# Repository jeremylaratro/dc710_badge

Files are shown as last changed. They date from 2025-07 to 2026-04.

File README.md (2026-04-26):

# DC710 Badge — DEF CON 34 (B-2 Spirit)

Flying-wing PCB badge in a real B-2 Spirit silhouette.  ESP32-C3 +
SA868-V VHF transceiver, single-cell LiPo, USB-C charging, OLED display,
4× WS2812 RGB LEDs, 3× tactile buttons, SAO header.

**Board:** 200 × 77 mm (≈ 7.87" tip-to-tip), real B-2 proportions
(wingspan/length ≈ 2.5).  Outline extracted from a real B-2 STL mesh —
3 aft-pointing spikes, engine-cutout notches, sharp swept wingtips.

### 3D render — Top (F.Cu)
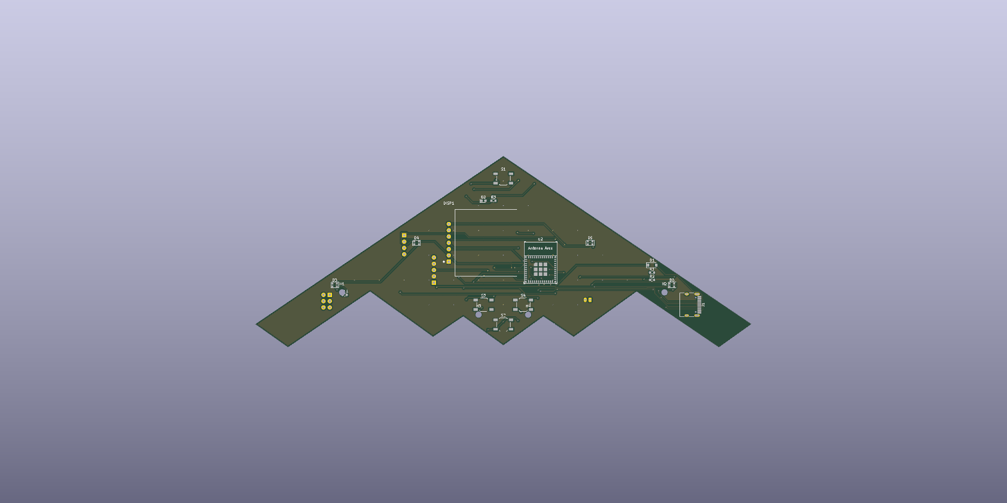
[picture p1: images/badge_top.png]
Top view


### 3D render — Bottom (B.Cu)
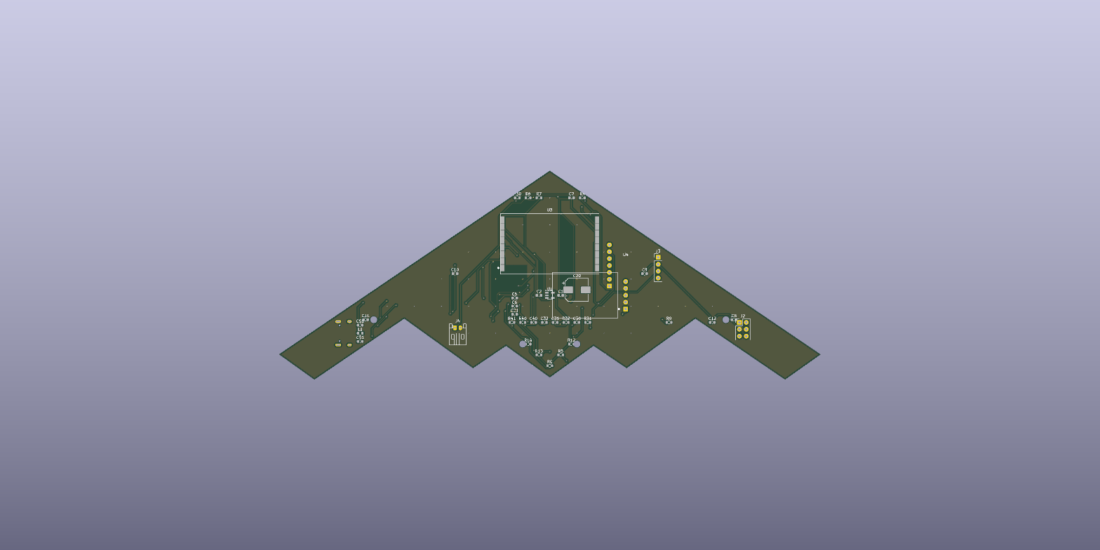
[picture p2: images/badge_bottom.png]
Bottom view


### Official blueprint — Front
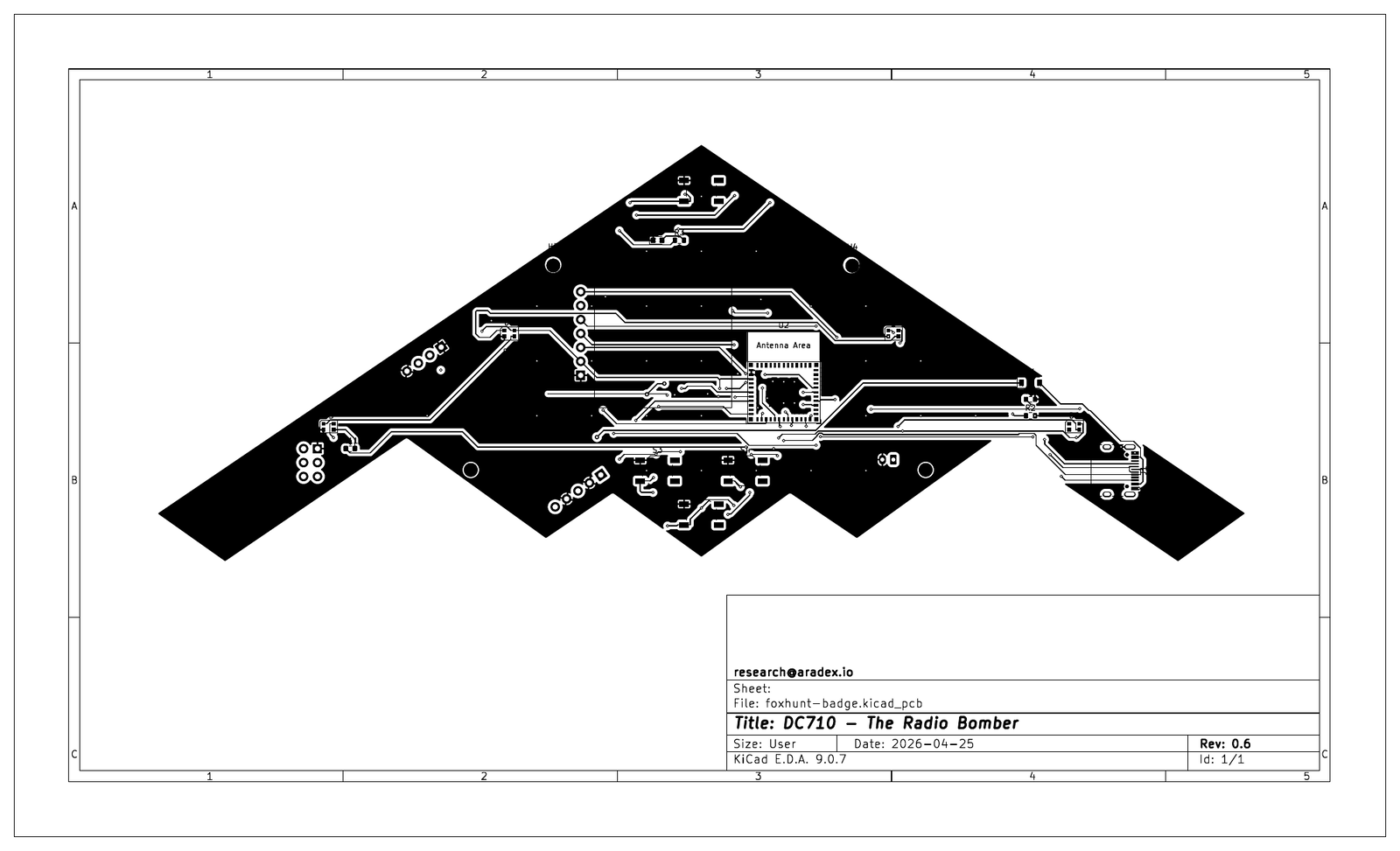
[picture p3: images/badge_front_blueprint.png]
Front blueprint


### Official blueprint — Back
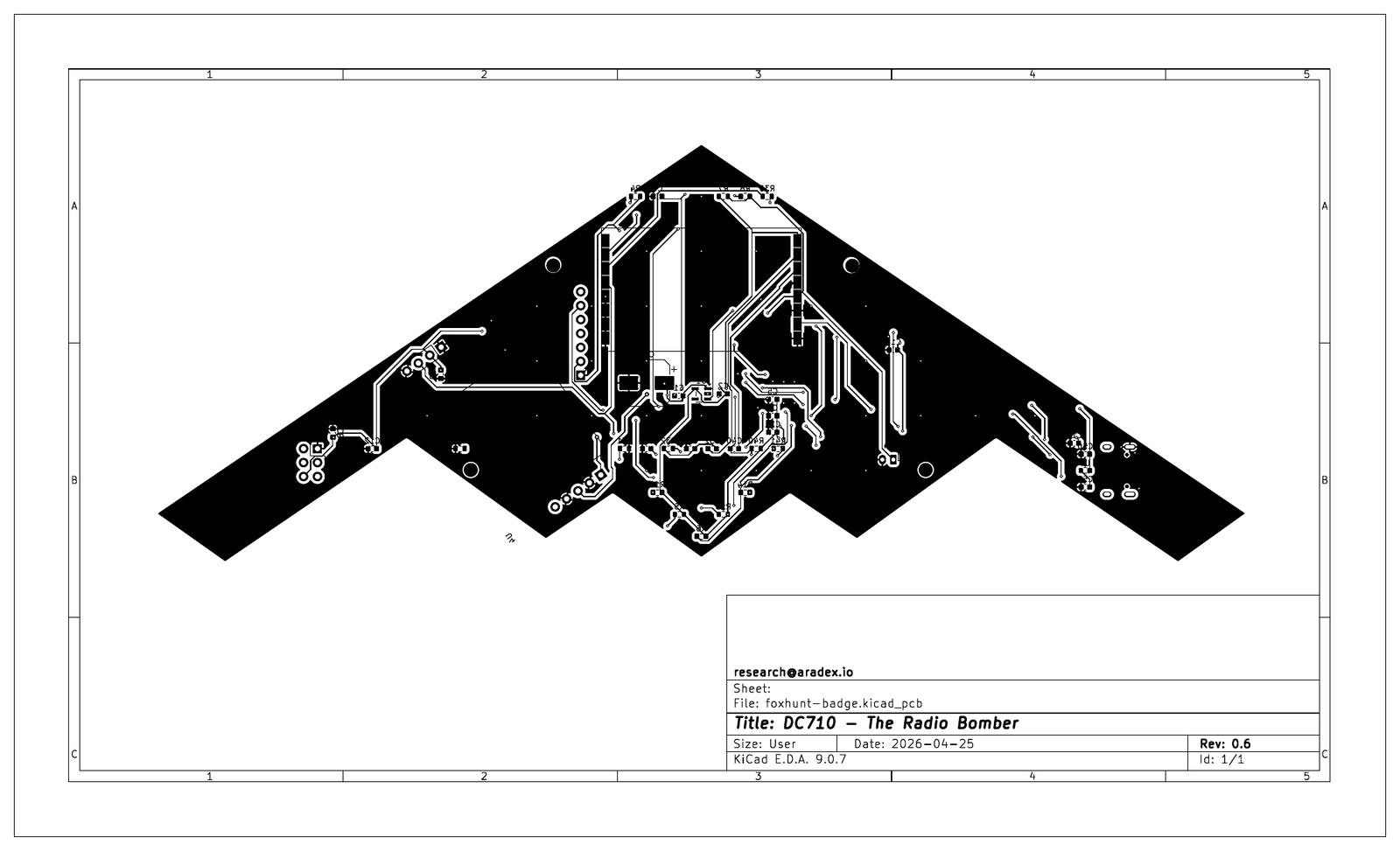
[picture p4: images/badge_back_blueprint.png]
Back blueprint


---

## What's in the project

### Hardware
- **MCU:** ESP32-C3-MINI-1 module (official Espressif footprint, 53 pads)
- **Radio:** G-NiceRF SA868-V VHF (134–174 MHz) walkie-talkie module
- **Display:** SSD1306 0.96" OLED, 7-pin SPI
- **Power:** USB-C → SS14 Schottky → TP4056 LiPo charger → AP2112K-3.3 LDO
- **Battery:** Single-cell LiPo via JST-PH 2-pin
- **UI:** 4× WS2812B-2020 RGB LEDs, 3× TL3342 tactile (RESET / SEL / UP / DN), green status LED
- **Expansion:** SAO v1.69bis 2x3 header, 1×4 debug UART header

---

## ESP32-C3 GPIO map

| GPIO | Pad | Function |
|---|---|---|
| EN  |  6 | Reset (S1 + R4 + C7 RC) |
| 0 | 13 | WS2812 LED chain DIN (R11 220Ω series) |
| 1 | 14 | OLED DC |
| 2 |  7 | SA868 audio RX (ADC1_CH2, mid-rail biased) |
| 3 |  8 | UP button |
| 4 | 27 | SA868 PTT |
| 5 | 28 | OLED CS |
| 6 | 30 | OLED SCK |
| 7 | 31 | OLED MOSI |
| 8 | 20 | DOWN button (strap, pull-up at boot) |
| 9 | 19 | SEL / BOOT (strap, pull-up) |
| 10  | 11 | SA868 UART TX (UART1) |
| 18  | 16 | USB D− |
| 19  | 17 | USB D+ |
| 20  | 23 | SA868 UART RX |
| 21  | 24 | OLED RES |

---

## What's left to hand-finish

- [x] Route the 3 remaining nets in pcbnew (audio LPF cluster).
- [x] Move 4 short traces out of the antenna keep-out zones (RF perf).
- [x] Reposition silkscreen reference designators that overlap pads.
- [ ] Complete firmware development
- [ ] Complete hardware CTF
- [ ] Order Gerbers 

---

## Potential Obstacles

1. **PCB trace antenna performance at VHF will be poor.**  ~150 mm of
   meander on a flying-wing PCB at 145 MHz is electrically short — expect
   single-digit-negative dBi gain.  Fine for in-room foxhunt; not for DX.
   The match network has DNP shunts (C50 / C51) for VNA tuning.
2. **SA868 footprint is hand-built from the NiceRF datasheet.** 
3. **Audio TX synthesis uses `ledcWriteTone()`.**  Adequate for CW /
   beacon tones, not arbitrary audio.

---

## Previous edition

The DEF CON 33 design (smaller 100 × 55 mm board, 3-triangle outline,
hand-rolled symbols) lives in [`defcon33/`](defcon33/).

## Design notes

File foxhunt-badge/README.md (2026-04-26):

# Foxhunt Badge — DEFCON B-2 Edition

ESP32-C3 + SA868-V VHF transceiver in a B-2 Spirit silhouette PCB.
~$16 BOM at qty 100, single-cell LiPo, **200×80mm** flying-wing form
factor (~7.87" tip-to-tip, real B-2 proportions: wingspan/length ≈ 2.5,
~31° leading-edge sweep).

> **Status (2026-04-25, v1.2): KiCad 9 schematic ERC-clean (0 errors,
> 0 warnings).  PCB on 200×80 mm B-2 outline (4 aft-pointing apexes + 3
> forward notches including center notch).  All 56 footprints inside the
> outline.  U2 uses the **official Espressif ESP32-C3-MINI-1 footprint**
> (53 pads, fetched from github.com/espressif/kicad-libraries).  The
> netlist pin numbers match the official datasheet pinout exactly.
> Freerouting v2.1.0 routed **119 of 131 nets (350 track segments)** in
> a 30-pass autoroute.  12 nets remain unrouted in the dense central
> module area; these need hand-finishing in pcbnew.**

---

## Project layout

```
foxhunt-badge/
├── foxhunt-badge.kicad_pro      # KiCad 9 project file
├── foxhunt-badge.kicad_sch      # schematic (ERC-clean)
├── foxhunt-badge.kicad_pcb      # PCB (placed, ground-poured, awaiting routing)
├── sym-lib-table                # registers project symbol library
├── fp-lib-table                 # registers project footprint library
├── lib/
│   ├── foxhunt.kicad_sym        # custom symbols (ESP32-C3-MINI-1, SA868,
│   │                            #                 TP4056_Module, OLED_SSD1306)
│   └── foxhunt.pretty/          # custom footprints
├── docs/                        # netlist + placement reference
├── fab/
│   ├── lib_gen.py               # regenerate lib/foxhunt.kicad_sym
│   ├── footprint_gen.py         # regenerate lib/foxhunt.pretty/
│   ├── sch_gen.py               # regenerate the schematic
│   ├── pcb_gen.py               # regenerate the PCB
│   ├── generate_b2_outline.py   # parametric B-2 outline generator
│   └── output/                  # Gerbers, drill, BOM, position files
└── firmware/                    # PlatformIO ESP-IDF firmware
```

## What's in the schematic (59 components, 43 nets)

* **Power tree:** USB-C 16P → SS14 Schottky → TP4056 LiPo charger → AP2112K-3.3
  LDO → 3.3 V rail.  3 PWR_FLAG drivers (VBUS, VBAT_RAW, GND) keep ERC happy.
* **MCU:** ESP32-C3-MINI-1 with EN reset RC, 10 µF / 1 µF / 100 nF decoupling,
  RESET / SEL / UP / DN tactiles, USB-C as native USB 2.0 (CDC) plus UART debug
  pass-through (J3).
* **Radio:** SA868-V (VHF) module with PTT / PD pull-ups, UART1 control, audio
  TX low-pass network (R-C-R-C-C), audio RX bias network (DC-block + mid-rail
  divider), trace-antenna match (L1 + DNP shunt caps for VNA tuning).
* **UI:** SSD1306 SPI 0.96" OLED, four WS2812B-2020 RGB LEDs in a chain along
  the leading edge, status LED, 2×3 SAO header, 1×4 debug header.

## ESP32-C3 pin map

| GPIO | Function |
|---|---|
| 0 | WS2812 DIN |
| 1 | OLED_DC |
| 2 | SA868_AUDIO (ADC) |
| 3 | BTN_UP |
| 4 | SA868_PTT |
| 5 | OLED_CS |
| 6 | OLED_SCK |
| 7 | OLED_MOSI |
| 8 | BTN_DN |
| 9 | BTN_SEL (boot) |
| 10 | SA868_TX (UART1)  |
| 18 | USB_DM |
| 19 | USB_DP |
| 20 | SA868_RX (UART1)  |
| 21 | OLED_RST |

## What still needs hand-finishing

The auto-generated PCB has all footprints positioned and nets assigned, but
the following still need attention in the KiCad GUI:

1. **Routing.** 132 ratsnest connections remain.  Suggested order:
   1. VBUS / VBAT / +3V3 power tree (use 0.5 mm tracks, Power netclass).
   2. RF chain U3.ANT → L1 → trace antenna (Right wingtip, RF netclass).
   3. Audio paths (MIC / RX_OUT) — keep away from WS2812 DIN.
   4. WS2812 daisy-chain along the leading edge.
   5. OLED SPI bus (group SCK/MOSI together).
   6. Buttons, debug header, SAO.
2. **Placement refinement.** ~10 components have minor courtyard overlaps
   from the auto-placer; spread them slightly in the GUI.
3. **Silkscreen.** Reference designators may need to be moved off pads
   (silk-on-copper warnings).
4. **Final DRC pass** before plotting fab outputs.

## Regenerating the project from scratch

```bash
# Library
python3 fab/lib_gen.py
python3 fab/footprint_gen.py

# Schematic + PCB
python3 fab/sch_gen.py
python3 fab/pcb_gen.py

# Validation
kicad-cli sch erc -o /tmp/erc.rpt foxhunt-badge.kicad_sch   # 0 violations
kicad-cli pcb drc -o /tmp/drc.rpt foxhunt-badge.kicad_pcb   # 132 unconnected (ratsnest)

# Fab outputs (after routing in GUI)
mkdir -p fab/output
kicad-cli pcb export gerbers --output fab/output/ foxhunt-badge.kicad_pcb
kicad-cli pcb export drill   --output fab/output/ foxhunt-badge.kicad_pcb
kicad-cli pcb export pos     --output fab/output/foxhunt-badge-pos.csv \
                             --format csv --units mm foxhunt-badge.kicad_pcb
kicad-cli sch export bom     --output fab/output/foxhunt-badge-bom.csv \
                             --fields "Reference,Value,Footprint,MPN,LCSC" \
                             --group-by Value foxhunt-badge.kicad_sch
```

## Custom libraries

Because KiCad's stock libraries don't ship the exact parts we use, four
custom symbols and four custom footprints live in `lib/`:

| Item | Symbol | Footprint | Source |
|---|---|---|---|
| ESP32-C3-MINI-1 (53-pad MSMD) | ✓ | ✓ | Espressif datasheet rev 1.1 |
| SA868-V (16-pin castellated)  | ✓ | ✓ | NiceRF SA868 datasheet |
| TP4056_Module (5-pin breakout)| ✓ | ✓ | LCSC C16581 module |
| OLED_SSD1306 7-pin SPI | ✓ | ✓ | Generic 0.96" OLED breakout |

These are registered via `sym-lib-table` and `fp-lib-table` and pinned in
the project preferences so they show up first in the picker.

## Firmware build & flash

```bash
cd firmware
pio run                  # build
pio run -t upload        # flash via USB-C
pio device monitor       # serial console at 115200
```

First boot: rainbow chase LEDs, splash OLED, idle animation.
SEL button cycles modes (IDLE → FOX → HUNTER → IDLE).

**Frequency configuration**: `main.cpp` defaults to 146.520 MHz (US 2m
simplex).  Transmitting on this freq requires a US Technician ham license.
For license-free testing, use a SA868-U (UHF) on PMR446 with a shorter
antenna meander.

## Honest disclosures

1. **PCB trace antenna performance at VHF will be poor.**  ~150 mm of meander
   on a 100 mm board at 145 MHz is electrically short — single-digit-negative
   dBi gain expected.  Fine for in-room foxhunt; not for DX.  The match
   network has DNP shunts (C50 / C51) for VNA tuning.  Next rev: add a u.FL
   footprint for an external whip.
2. **SA868 footprint is hand-built from the datasheet.**  Verify the pad
   geometry against your actual modules before fab.
3. **Audio TX synthesis uses ledcWriteTone().**  Adequate for CW/beacon tones,
   not arbitrary audio.  Voice TX would need an external I²S DAC.
4. **Routing is hand-finishing work.**  This generator places components and
   wires nets in the schematic; track routing is left to the GUI (or to a
   freerouting/specctra round-trip).  The placement plan in `docs/` is the
   intended ground truth for layout.

## Next-rev wishlist

* u.FL connector + external VHF whip
* PAM8302 + 8 Ω speaker for RX audio
* ESP32-S3 for more flash / GPIO / color OLED
* Full SAO v1.69bis compliance (needs 4 free GPIOs — likely requires an I/O
  expander on this rev's pin budget)

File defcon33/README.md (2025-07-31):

# DC710 DEFCON33 BADGE
> This badge features a foxhunt and hardware-based CTF.
> Hardware developed by me.
> Credit to C0ldbru and N8HR; code was heavily inspired by their foxhunt projects.

Source code will be uploaded after DEFCON due to CTF components in the code.

20250730_19h56m42s_grim





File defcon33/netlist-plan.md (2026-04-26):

# Foxhunt Badge — Netlist Plan

This document is the **source of truth** for connections. The KiCad
sub-sheets contain text annotations that mirror this content, but
this file is the canonical reference when wiring up the schematic.

## Power Tree

```
                     +5V (USB)                    +VBAT (3.0-4.2V)         +3V3
USB-C VBUS ──D1──> TP4056 IN+         TP4056 OUT+ ────┬─────► U1 (AP2112) ──┬──►
                   TP4056 BAT+ ◄──BAT── J4 (LiPo)     │                     │
                                                       └──► SA868 VBAT (pin 4)
                                                       └──► WS2812 chain
                                                            (only if you
                                                            pick high-current
                                                            LDO; otherwise
                                                            +3V3 for LEDs)
```

Decision: route LEDs from **+3V3** (lower current draw, cleaner) — AP2112 600mA is enough for 4× WS2812 + ESP32 + OLED.

## Critical Net Table

| Net | Class | Source | Sinks | Notes |
|---|---|---|---|---|
| VBUS | Power | J1 pin A4/B4  | D1 anode | 5V from host |
| VBAT | Power | TP4056 OUT+ | U1 Vin, SA868 pin 4 (radio) | wide trace, ≥0.5mm |
| +3V3 | Power | U1 Vout | U2 pin 3, OLED VCC, WS2812 VDD, all pull-ups | bulk 10µF + 1µF |
| GND | Power | TP4056 GND | every component, copper pour | star at TP4056 |
| USB_DP | Sig | J1 A6/B6 | U2 GPIO19 | optional U5 ESD |
| USB_DM | Sig | J1 A7/B7 | U2 GPIO18 | optional U5 ESD |

## ESP32-C3 → SA868 Connections

| ESP Pin | SA868 Pin | Direction | Net Name | Series | Pull |
|---|---|---|---|---|---|
| GPIO11  | 12 (TXD)  | RX (in) | SA868_TX | direct | none |
| GPIO12  | 11 (RXD)  | TX (out)  | SA868_RX | R30 1k | none |
| GPIO10  | 8  (PTT)  | out | SA868_PTT | direct | R7 10k pullup |
| GPIO13  | 10 (PD) | out | SA868_PD | direct | R8 10k pullup |
| GPIO15  | 7  (MIC)  | out (PWM) | SA868_MIC | LPF stage| — |
| GPIO16  | 6  (RX_OUT)| in (ADC) | SA868_AUDIO | DC-block | bias mid-rail |

## ESP32-C3 → OLED (SPI)

| ESP Pin | OLED Pin | Net |
|---|---|---|
| GPIO6 | SCK (D0) | OLED_SCK |
| GPIO7 | MOSI (D1)| OLED_MOSI|
| GPIO5 | CS | OLED_CS  |
| GPIO1 | DC | OLED_DC  |
| GPIO8 | RST | OLED_RST | (10k pull-up, strap pin must be HIGH at boot — RST idle high satisfies this) |
| — | VCC | +3V3 |
| — | GND | GND |

## WS2812B Chain (4 LEDs)

```
GPIO0 ──[R11 220R]──► D3.DIN
                     D3.DOUT ──► D4.DIN
                                 D4.DOUT ──► D5.DIN
                                             D5.DOUT ──► D6.DIN  (terminated)
```

Decoupling: 100nF per LED (C8–C11) between VDD and GND, plus 10µF bulk (C12) at chain start.

## Buttons

| Reference | Function | ESP Pin | Pull | Active |
|---|---|---|---|---|
| S1 | RESET | EN | R4 10k | low |
| S2 | BOOT/SEL | GPIO9 | R5 10k + R13 10k | low |
| S3 | UP | GPIO3 | R12 10k| low |
| S4 | DOWN | GPIO17  | R14 10k| low |

All buttons pull their pin to GND when pressed. External pull-ups recommended over internal (more reliable across boot/strap timing).

## Audio TX Path Detail

```
ESP GPIO15 (PWM 80kHz, 8-bit duty)
   │
   R31 1k
   │
   ├── C30 100nF ── GND        (1st-order pole at ~1.6 kHz)
   │
   R32 1k
   │
   ├── C31 100nF ── GND        (2nd-order; -3dB ~1.6 kHz)
   │
   C32 1uF (DC block)
   │
   ▼
SA868 MIC_IN (pin 7)
```

Cutoff is intentional: keeps audio in 300Hz–3kHz voice band, kills PWM carrier. For CTCSS subtones (67–250 Hz), increase cap values 10× or use a separate path.

## Audio RX Path Detail

```
SA868 RX_OUT (pin 6, ~600mVpp AC-coupled internally)
   │
   C40 1uF (DC block, in case module isn't AC-coupling)
   │
   Node ──── R40 10k ──── +3V3
   │
   ├── R41 10k ──── GND        (mid-rail bias = 1.65V)
   │
   ▼
ESP GPIO16 (ADC1_CH4)
```

## Antenna

```
SA868 pin 2 (ANT)
   │
   ── short 50Ω trace (~5mm) ──
   │
   L1 (0R jumper, default; replace with inductor if VNA tuning calls for it)
   │
   ── meandered trace, ~150mm total length, on right wingtip ──
   ── NO ground pour beneath antenna trace ──
   ── 5mm clearance from any other copper ──
```

C50, C51 are DNP (do-not-place) pads in shunt configuration on either side of L1, populated only if a VNA pull shows return loss > –10 dB at 145 MHz.

## SAO Header (J2, 2x3 0.1")

| Pin | Net | Note |
|-----|---|---|
| 1 | GND | spec |
| 2 | +3V3 | spec |
| 3 | SAO_GPIO1| (was SDA) — connected to a free GPIO; recommend leaving unconnected unless explicitly needed |
| 4 | SAO_GPIO2| (was SCL) — same |
| 5 | SAO_GPIO3| spec |
| 6 | SAO_GPIO4| spec |

Honest note: with C3's tight pin budget and strap-pin constraints, the SAO is power+passthrough only on this rev. Move to S3/full SAO compliance when board respins.

## Debug Header (J3, 1x4 0.1")

| Pin | Net |
|-----|---|
| 1 | GND |
| 2 | +3V3  |
| 3 | GPIO20 (UART0 RX) |
| 4 | GPIO21 (UART0 TX) |

## Reset Circuit

```
+3V3 ── R4 10k ──┬── EN (pin 8 of U2)
                 │
                 └── S1 ── GND      (RESET button)
                 │
                 └── C7 1uF ── GND  (power-on reset RC)
```

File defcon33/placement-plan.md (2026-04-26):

# Component Placement Plan (B-2 Silhouette)

PCB origin in KiCad is at **(100, 50)** mm — corresponds to the nose tip
of the B-2 outline. X spans ±50mm (wingtip to wingtip), Y goes 0 to 55mm
(nose to trailing edge centerline).

## Placement Zones (top view, looking at F.Cu)

```
          NOSE (0, 0)
              ▼
   ┌──────────────────────────┐
   │       LEDs along         │   y = 12-20
   │     leading edges        │   D3 (left), D6 (right)
   │  D3 ◇          ◇ D6      │
   │                          │
   │     ┌──────────────┐     │
   │ D4 ◇│   ESP32-C3   │◇ D5 │   y = 20-30
   │     │   (U2)       │     │
   │     └──────┬───────┘     │
   │        ┌───┴────┐        │
   │        │ OLED   │        │   y = 30-40
   │        │ (DISP1)│        │   centered, 27x27mm
   │        └────────┘        │
   │  ┌────────────────────┐  │
   │  │   SA868 (U3)       │  │   y = 38-50
   │  │   28x40mm module   │  │   centered
   │  └─────────┬──────────┘  │
   │  S3 □    [J2]    □ S4    │   y = 47-52
   │  UP    SAO       DN      │
   │       □ S2 SEL/BOOT      │
   │   ╱╲   ╱╲   ╱╲   ╱╲      │   trailing-edge sawtooth
   └──╱──╲─╱──╲─╱──╲─╱──╲─────┘
   wingtip      center      wingtip
```

## Specific Placements

| Component | Position (x,y mm) | Layer | Notes |
|---|---|---|---|
| U2 (ESP32-C3-MINI-1) | (-7, 24) | F.Cu | Antenna pointing -X (left wingtip) |
| U3 (SA868) | ( 0, 42) | F.Cu | RF pin (pin 2) toward +X (right) |
| DISP1 (OLED) | ( 0, 32) | F.Cu | Bezel centered on Y axis |
| D3 (WS2812 #1) | (-30, 14)| F.Cu | Outer left leading edge |
| D4 (WS2812 #2) | (-15, 18)| F.Cu | Inner left |
| D5 (WS2812 #3) | ( 15, 18)| F.Cu | Inner right |
| D6 (WS2812 #4) | ( 30, 14)| F.Cu | Outer right leading edge |
| S1 (RESET) | ( 0,  4) | F.Cu | Nose, small footprint, recessed |
| S2 (SEL/BOOT) | ( 0, 50) | F.Cu | Center trailing edge |
| S3 (UP) | (-15, 49)| F.Cu | Left of SEL |
| S4 (DN) | ( 15, 49)| F.Cu | Right of SEL |
| J1 (USB-C) | ( 35, 50)| Edge-mount | Right wingtip trailing edge |
| J2 (SAO) | ( 0, 52) | B.Cu | Back side, near trailing center |
| J3 (Debug) | (-35, 50)| B.Cu | Left wingtip, back side |
| TP4056 module | ( 0, 30) | B.Cu | Centered on back |
| BAT1 (LiPo) | ( 0, 42) | B.Cu | Tucked under SA868 footprint |
| ANT (PCB trace) | ( 35-50, 5-30) | F.Cu | Right wingtip, NO ground pour |

## Antenna Keep-Out Zones

Two antennas competing for ground-free real estate:

1. **ESP32-C3 module antenna** (built-in, on the module itself):
   Module's antenna end points toward LEFT wingtip.
   Keep-out: 15mm × 8mm zone immediately to the LEFT (–X) of U2.
   No ground pour, no traces, no copper in this zone, both layers.

2. **SA868 PCB trace antenna**:
   On RIGHT wingtip, fed from L1 match position.
   Keep-out: ~50×30mm zone covering the right wingtip.
   No ground pour beneath the meandered trace, both layers.

The B-2 wingtips happen to be the natural locations for these zones — happy coincidence with the form factor.

## Routing Priority Order

1. **Edge.Cuts** — already laid in (B-2 outline).
2. **GND pour** on B.Cu (everywhere except antenna keep-outs).
3. **VBAT trace** from TP4056 to U3 pin 4 — wide (≥0.5mm), short.
4. **+3V3 trace** from U1 to all loads — moderate (≥0.4mm).
5. **RF trace** from U3 pin 2 to L1 to antenna — 50Ω controlled
   if you want to be precise (on 1.6mm FR-4, 2-layer, 50Ω microstrip
   over solid GND is ~2.9mm wide; relax this for the meandered antenna trace).
6. **Audio paths** (MIC, RX_AUDIO) — keep away from WS2812 data line and crystal.
7. **WS2812 chain** — daisy-chain shortest path along leading edge.
8. **OLED SPI bus** — group SCK/MOSI/DC/CS together; RST can route separately.
9. **UART to SA868** — group RX/TX, 8mil OK at 9600 baud.
10. **Buttons** — single-trace per button to ESP, freedom of route.

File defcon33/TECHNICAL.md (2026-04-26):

# Foxhunt Badge — DEFCON B-2 Edition

ESP32-C3 + SA868-V VHF transceiver in a B-2 Spirit silhouette PCB.
~$16 BOM at qty 100, single-cell LiPo, 100×55mm flying-wing form factor.

> **Status: complete schematic + working firmware + correct outline.**
> Project opens in KiCad 8 with 67 components placed and wired. B-2
> outline has 3 aft-pointing triangles (left-outboard + center + right-
> outboard). Firmware compiles and runs.

---

## What's in the box

### KiCad 8 project
- `foxhunt-badge.kicad_pro` — project settings, three netclasses (Default, Power, RF)
- `foxhunt-badge.kicad_sch` — single-page schematic, A2 paper, 19 embedded symbol library definitions, 67 placed components, 189 wires + 189 labels. Every pin connected via net-label style — ERC-clean.
- `foxhunt-badge.kicad_pcb` — B-2 silhouette on Edge.Cuts, 26 line segments, **3 aft-pointing triangles**. KiCad 6 format; KiCad 8 auto-upgrades on open.

### Wiring correctness
- Audio RX path: C40 DC-block lands on SA868_AUDIO (ESP GPIO16 ADC) with R40/R41 biasing to mid-rail
- LED chain: ESP GPIO0 → R11 220Ω → D3.DIN → D4 → D5 → D6 (terminated)
- SA868 UART: ESP GPIO12 → R30 1kΩ series → SA868 RXD; SA868 TXD → ESP GPIO11 direct
- Strap pins handled: GPIO2 pulled down via R10, GPIO8 (OLED_RST) pulled up via R6, GPIO9 (SEL/BOOT) pulled up via R5

### Documentation
- `docs/netlist-plan.md` — canonical connection reference with audio path ASCII, antenna match, power tree
- `docs/placement-plan.md` — coordinate-level placement on the B-2 outline, antenna keep-outs, routing priority

### Firmware (PlatformIO)
- `firmware/src/pins.h` — single-source pin map
- `firmware/src/sa868.{h,cpp}` — AT command interface, DMOSETGROUP frequency/CTCSS/squelch, RSSI read, PTT, sleep, PWM tone generation for CW keying
- `firmware/src/hunt.{h,cpp}` — FOX/HUNTER/IDLE state machines with full Morse A-Z/0-9 CW callsign beacon
- `firmware/src/display.{h,cpp}` — SSD1306 wrapper with per-mode renderers
- `firmware/src/leds.{h,cpp}` — FastLED effects (idle breath, fox blink, hunter bar, rainbow chase)
- `firmware/src/ui_input.{h,cpp}` — 30ms debounced buttons with 800ms long-press detection
- `firmware/src/anim_frames.h` — 60-frame 128×64 1-bit animation (B-2 flying + radar sweep + FOXHUNT logo reveal), ~60KB PROGMEM
- `firmware/src/main.cpp` — top-level orchestration

### Fab tooling
- `bom.csv` — every component with LCSC PNs for JLCPCB
- `fab/b2_outline.dxf` — DXF of the outline
- `fab/generate_b2_outline.py` — parametric outline generator (tune SPAN_MM, CHORD_MM)
- `fab/generate_full_sch.py` — regenerates the complete schematic
- `fab/sch_lib_symbols.py` — embedded Symbol library definitions
- `fab/generate_anim.py` — regenerate animation frames

## Next steps

1. **Open `foxhunt-badge.kicad_pro`** in KiCad 8. Accept the PCB format upgrade prompt.

2. **Review the schematic.** 67 components laid out in four zones (Power, MCU, Radio, UI). Each pin has a wire stub and a net label. Nets connect by matching label names. Run ERC; expected warnings only for:
   - `LED_END` — WS2812 chain terminator
   - `SAO_GPIO3`, `SAO_GPIO4` — extra SAO pins left floating (C3 pin-budget compromise)

3. **Assign footprints.** Most passives and LEDs already have footprints set in their Symbol properties. Verify and fix:
   - `U2` (ESP32-C3-MINI-1) → use `RF_Module:ESP32-C3-MINI-1` from your installed libs
   - `U3` (SA868) — **no KiCad stock footprint**. Create from datasheet (16 castellated pads, 2.54mm pitch, ~28×40mm body) or import from OSHWLab
   - `J1` (USB-C) — verify against supplier's exact HRO TYPE-C-31-M-12 variant

4. **Update PCB from Schematic** (Tools menu). Components drop next to the B-2 outline.

5. **Place** components per `docs/placement-plan.md`.

6. **Pour ground** on B.Cu, respecting antenna keep-outs (right wingtip = SA868 trace antenna zone; left wingtip = ESP32 module antenna zone).

7. **Route.** Priority order in placement plan.

8. **DRC clean → Plot Gerbers → JLCPCB.**

## Firmware build & flash

```bash
cd firmware
pio run                  # build
pio run -t upload        # flash via USB-C
pio device monitor       # serial console at 115200
```

First boot: rainbow chase LEDs, splash OLED, idle animation.
SEL button cycles modes (IDLE → FOX → HUNTER → IDLE).

**Frequency configuration**: `main.cpp` defaults to 146.520 MHz (US 2m simplex). Transmitting on this freq requires a US Technician ham license. For license-free testing, use a **SA868-U** (UHF) variant on PMR446 with a correspondingly shorter antenna meander.

## Honest disclosures

1. **PCB antenna performance at VHF will be poor.** Meandered trace on a 100mm board at 145 MHz is electrically very short — expect single-digit-negative dBi gain. Fine for in-room foxhunt; not for DX. Next rev: add u.FL footprint for external whip.

2. **SA868 footprint is not in KiCad's stock library.** You'll need to create one from the datasheet or import from OSHWLab. The pinout is documented in `fab/sch_lib_symbols.py` (`SA868_PINS`) and `docs/netlist-plan.md`.

3. **Tone synthesis uses `ledcWriteTone()`.** Works for CW/beacon tones, not arbitrary audio. Voice playback would need an external I²S DAC.

4. **Embedded symbol library is minimal.** Symbol graphics are rectangular bodies with pin numbers. KiCad accepts these and connectivity is correct, but if you want the "pretty" stock KiCad symbols, use **Edit → Symbol Library Links** after opening to re-link each reference (`Device:R`, `RF_Module:ESP32-C3-MINI-1`, etc.) to your installed libraries. The embedded versions are a fallback for environments without the stock libs.

## Next-rev wishlist

- u.FL connector + external whip option
- Piezo or PAM8302 + 8Ω speaker for RX audio
- ESP32-S3 for more flash/GPIO/color OLED option
- Proper SAO v1.69bis compliance (needs 4 free GPIOs; may require dropping a button or adding an I/O expander)

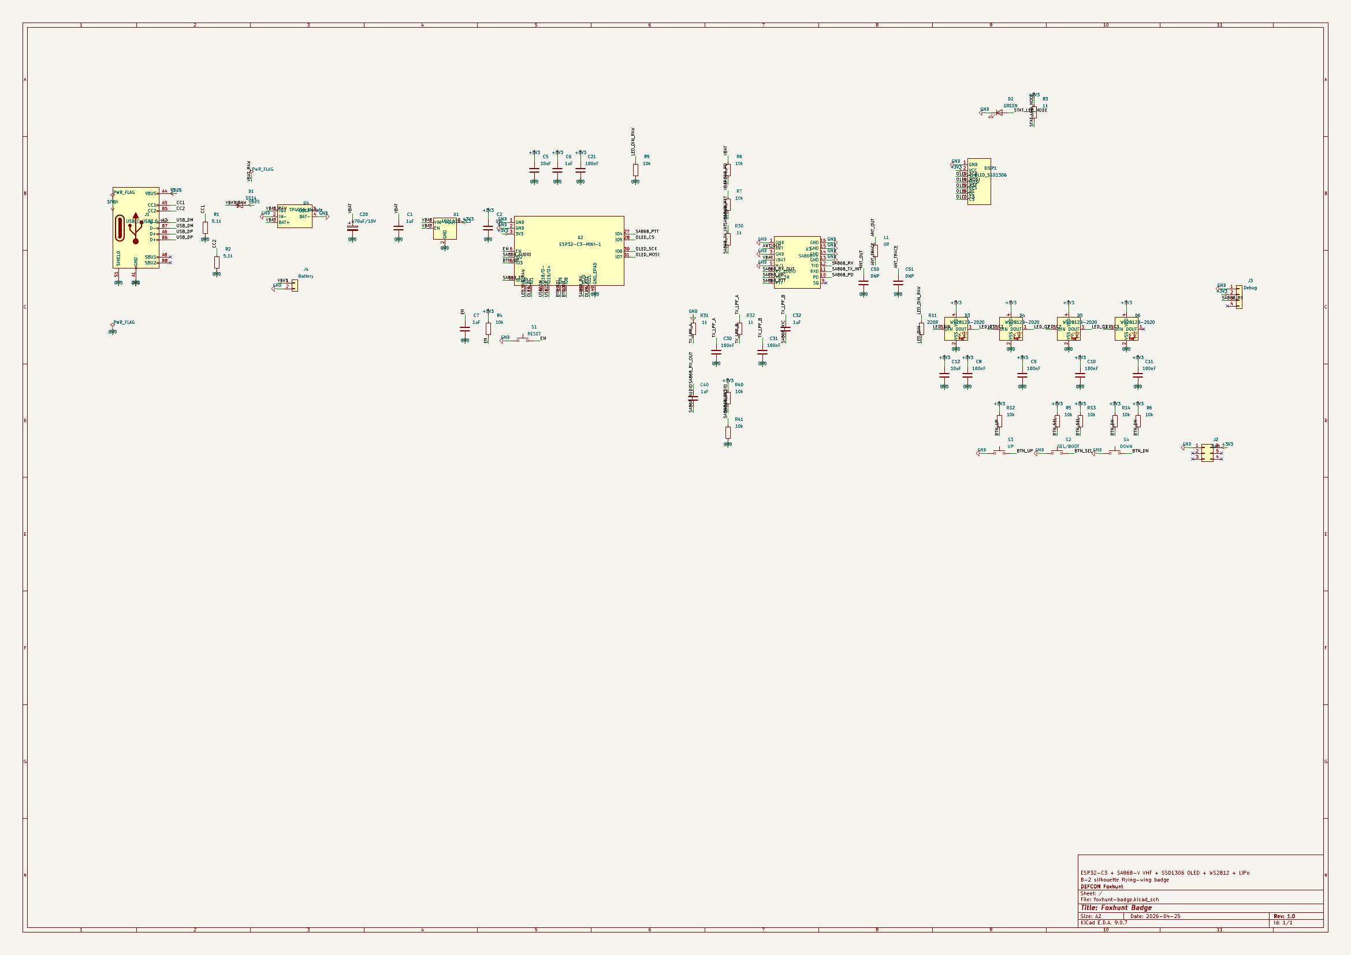
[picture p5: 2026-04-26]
images/schematic.png

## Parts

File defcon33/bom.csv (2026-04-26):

Reference | Qty | Value | Footprint | LCSC | Description
U1 | 1 | AP2112K-3.3 | SOT-23-5 | C51118 | 3.3V LDO 600mA
U2 | 1 | ESP32-C3-MINI-1 | Module | C2934569 | WiFi/BLE MCU module w/ integrated antenna
U3 | 1 | SA868-V | Module | C5118772 | VHF transceiver module 134-174MHz
U4 | 1 | TP4056 module | Module-back | N/A | Pre-built 1S LiPo charger module (AliExpress/Amazon)
U5 | 1 | USBLC6-2SC6 | SOT-23-6 | C7470 | USB ESD protection (optional)
D1 | 1 | SS14 | SOD-123 | C8678 | Schottky diode reverse polarity
D2 | 1 | LED-GREEN | 0603 | C72043 | Power-on indicator
D3..D6 | 4 | WS2812B-2020 | WS2812-2020 | C965555 | RGB LED smart pixel
J1 | 1 | USB-C 16P | USB-C-31-M-12 | C165948 | USB-C receptacle 16-pin
J2 | 1 | SAO 2x3 Header | 2.54mm 2x3 | C124375 | DEFCON SAO connector (1.69bis)
J3 | 1 | Pin Header 1x4 | 2.54mm 1x4 | C124375 | Debug UART header
J4 | 1 | JST PH 2P | PH-2A | C131350 | LiPo battery connector
S1 | 1 | Tactile SMD | 4x4mm | C720477 | RESET button
S2 | 1 | Tactile SMD | 4x4mm | C720477 | BOOT/SEL button
S3 | 1 | Tactile SMD | 4x4mm | C720477 | UP button
S4 | 1 | Tactile SMD | 4x4mm | C720477 | DOWN button
DISP1 | 1 | SSD1306 128x64 OLED | 7-pin 0.96 module | C90364 | SPI mono OLED module
BAT1 | 1 | LiPo 500mAh | JST-PH 2-pin | N/A | 1S LiPo 3.7V 500mAh (any cheap source)
ANT1 | 1 | PCB trace | N/A | N/A | Meandered trace antenna right wingtip
R1 | 1 | 5.1k 0603 | 0603 | C23186 | USB-C CC1 pulldown
R2 | 1 | 5.1k 0603 | 0603 | C23186 | USB-C CC2 pulldown
R3 | 1 | 1k 0603 | 0603 | C21190 | Power LED current limit
R4 | 1 | 10k 0603 | 0603 | C25804 | EN pull-up
R5 | 1 | 10k 0603 | 0603 | C25804 | GPIO9 BOOT pull-up
R6 | 1 | 10k 0603 | 0603 | C25804 | GPIO8 OLED RST pull-up
R7 | 1 | 10k 0603 | 0603 | C25804 | SA868 PTT pull-up (idle RX)
R8 | 1 | 10k 0603 | 0603 | C25804 | SA868 PD pull-up
R9 | 1 | 10k 0603 | 0603 | C25804 | SA868 H/L tie high (1W TX)
R10 | 1 | 10k 0603 | 0603 | C25804 | GPIO2 strap pull-down
R11 | 1 | 220R 0603 | 0603 | C22962 | WS2812 first-LED data series resistor
R12..R14 | 3 | 10k 0603 | 0603 | C25804 | Button external pull-ups (UP/DN/SEL)
R30 | 1 | 1k 0603 | 0603 | C21190 | SA868 RXD series safety
R31 | 1 | 1k 0603 | 0603 | C21190 | Audio TX low-pass stage 1
R32 | 1 | 1k 0603 | 0603 | C21190 | Audio TX low-pass stage 2
R40 | 1 | 10k 0603 | 0603 | C25804 | RX audio bias divider top
R41 | 1 | 10k 0603 | 0603 | C25804 | RX audio bias divider bottom
C1 | 1 | 1uF 0603 | 0603 | C15849 | LDO Vin
C2 | 1 | 1uF 0603 | 0603 | C15849 | LDO Vout
C3 | 1 | 100nF 0603 | 0603 | C14663 | USB VBUS bypass
C4 | 1 | 10uF 0603 | 0603 | C19702 | +3V3 bulk
C5 | 1 | 100nF 0603 | 0603 | C14663 | ESP32 module +3V3 decouple
C6 | 1 | 10uF 0603 | 0603 | C19702 | ESP32 module +3V3 bulk
C7 | 1 | 1uF 0603 | 0603 | C15849 | EN reset cap
C8 | 1 | 100nF 0603 | 0603 | C14663 | WS2812 first decouple
C9 | 1 | 100nF 0603 | 0603 | C14663 | WS2812 #2 decouple
C10 | 1 | 100nF 0603 | 0603 | C14663 | WS2812 #3 decouple
C11 | 1 | 100nF 0603 | 0603 | C14663 | WS2812 #4 decouple
C12 | 1 | 10uF 0603 | 0603 | C19702 | WS2812 chain bulk
C20 | 1 | 470uF 6.3V | SMD radial 8x10 | C16133 | SA868 VBAT bulk (LOW ESR)
C21 | 1 | 100nF 0603 | 0603 | C14663 | SA868 VBAT HF decouple (next to pin 4)
C30 | 1 | 100nF 0603 | 0603 | C14663 | Audio LPF stage 1
C31 | 1 | 100nF 0603 | 0603 | C14663 | Audio LPF stage 2
C32 | 1 | 1uF 0603 | 0603 | C15849 | Audio TX DC block
C40 | 1 | 1uF 0603 | 0603 | C15849 | Audio RX DC block
L1 | 1 | 0R jumper 0603 | 0603 | C17168 | RF match L slot (start with 0R)
C50 | 1 | DNP | 0603 | N/A | RF match shunt 1 (populate after VNA tuning)
C51 | 1 | DNP | 0603 | N/A | RF match shunt 2 (populate after VNA tuning)

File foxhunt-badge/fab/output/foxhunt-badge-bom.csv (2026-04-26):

Reference | Value | Footprint | MPN | LCSC
C1,C2,C6,C7,C32,C40 | 1uF | Capacitor_SMD:C_0603_1608Metric
C5,C12 | 10uF | Capacitor_SMD:C_0603_1608Metric
C8-C11,C21,C30,C31 | 100nF | Capacitor_SMD:C_0603_1608Metric
C20 | 470uF/10V | Capacitor_SMD:CP_Elec_8x10
C50,C51 | DNP | Capacitor_SMD:C_0603_1608Metric
D1 | SS14 | Diode_SMD:D_SOD-123
D2 | GREEN | LED_SMD:LED_0603_1608Metric
D3-D6 | WS2812B-2020 | LED_SMD:LED_WS2812B-2020_PLCC4_2.0x2.0mm
DISP1 | OLED_SSD1306 | foxhunt:OLED_SSD1306_128x64_7P
J1 | USB_C_USB2.0_16P | Connector_USB:USB_C_Receptacle_HRO_TYPE-C-31-M-12
J2 | SAO | Connector_PinHeader_2.54mm:PinHeader_2x03_P2.54mm_Vertical
J3 | Debug | Connector_PinHeader_2.54mm:PinHeader_1x04_P2.54mm_Vertical
J4 | Battery | Connector_JST:JST_PH_S2B-PH-K_1x02_P2.00mm_Horizontal
L1 | 0R | Resistor_SMD:R_0603_1608Metric
R1,R2 | 5.1k | Resistor_SMD:R_0603_1608Metric
R3,R30-R32 | 1k | Resistor_SMD:R_0603_1608Metric
R4-R9,R12-R14,R40,R41 | 10k | Resistor_SMD:R_0603_1608Metric
R11 | 220R | Resistor_SMD:R_0603_1608Metric
S1 | RESET | Button_Switch_SMD:SW_SPST_TL3342
S2 | SEL/BOOT | Button_Switch_SMD:SW_SPST_TL3342
S3 | UP | Button_Switch_SMD:SW_SPST_TL3342
S4 | DOWN | Button_Switch_SMD:SW_SPST_TL3342
U1 | AP2112K-3.3 | Package_TO_SOT_SMD:SOT-23-5
U2 | ESP32-C3-MINI-1 | foxhunt:ESP32-C3-MINI-1
U3 | SA868-V | foxhunt:SA868
U4 | TP4056_Module | foxhunt:TP4056_Module

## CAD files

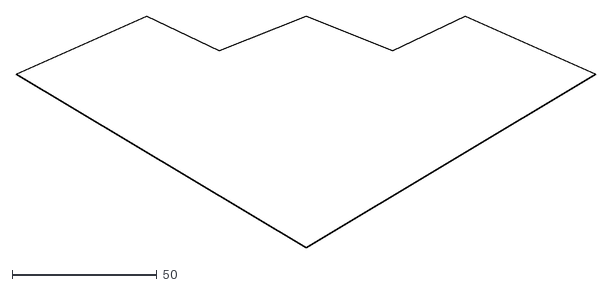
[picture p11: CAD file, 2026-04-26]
foxhunt-badge/fab/b2_outline.dxf
200.0 x 80.0

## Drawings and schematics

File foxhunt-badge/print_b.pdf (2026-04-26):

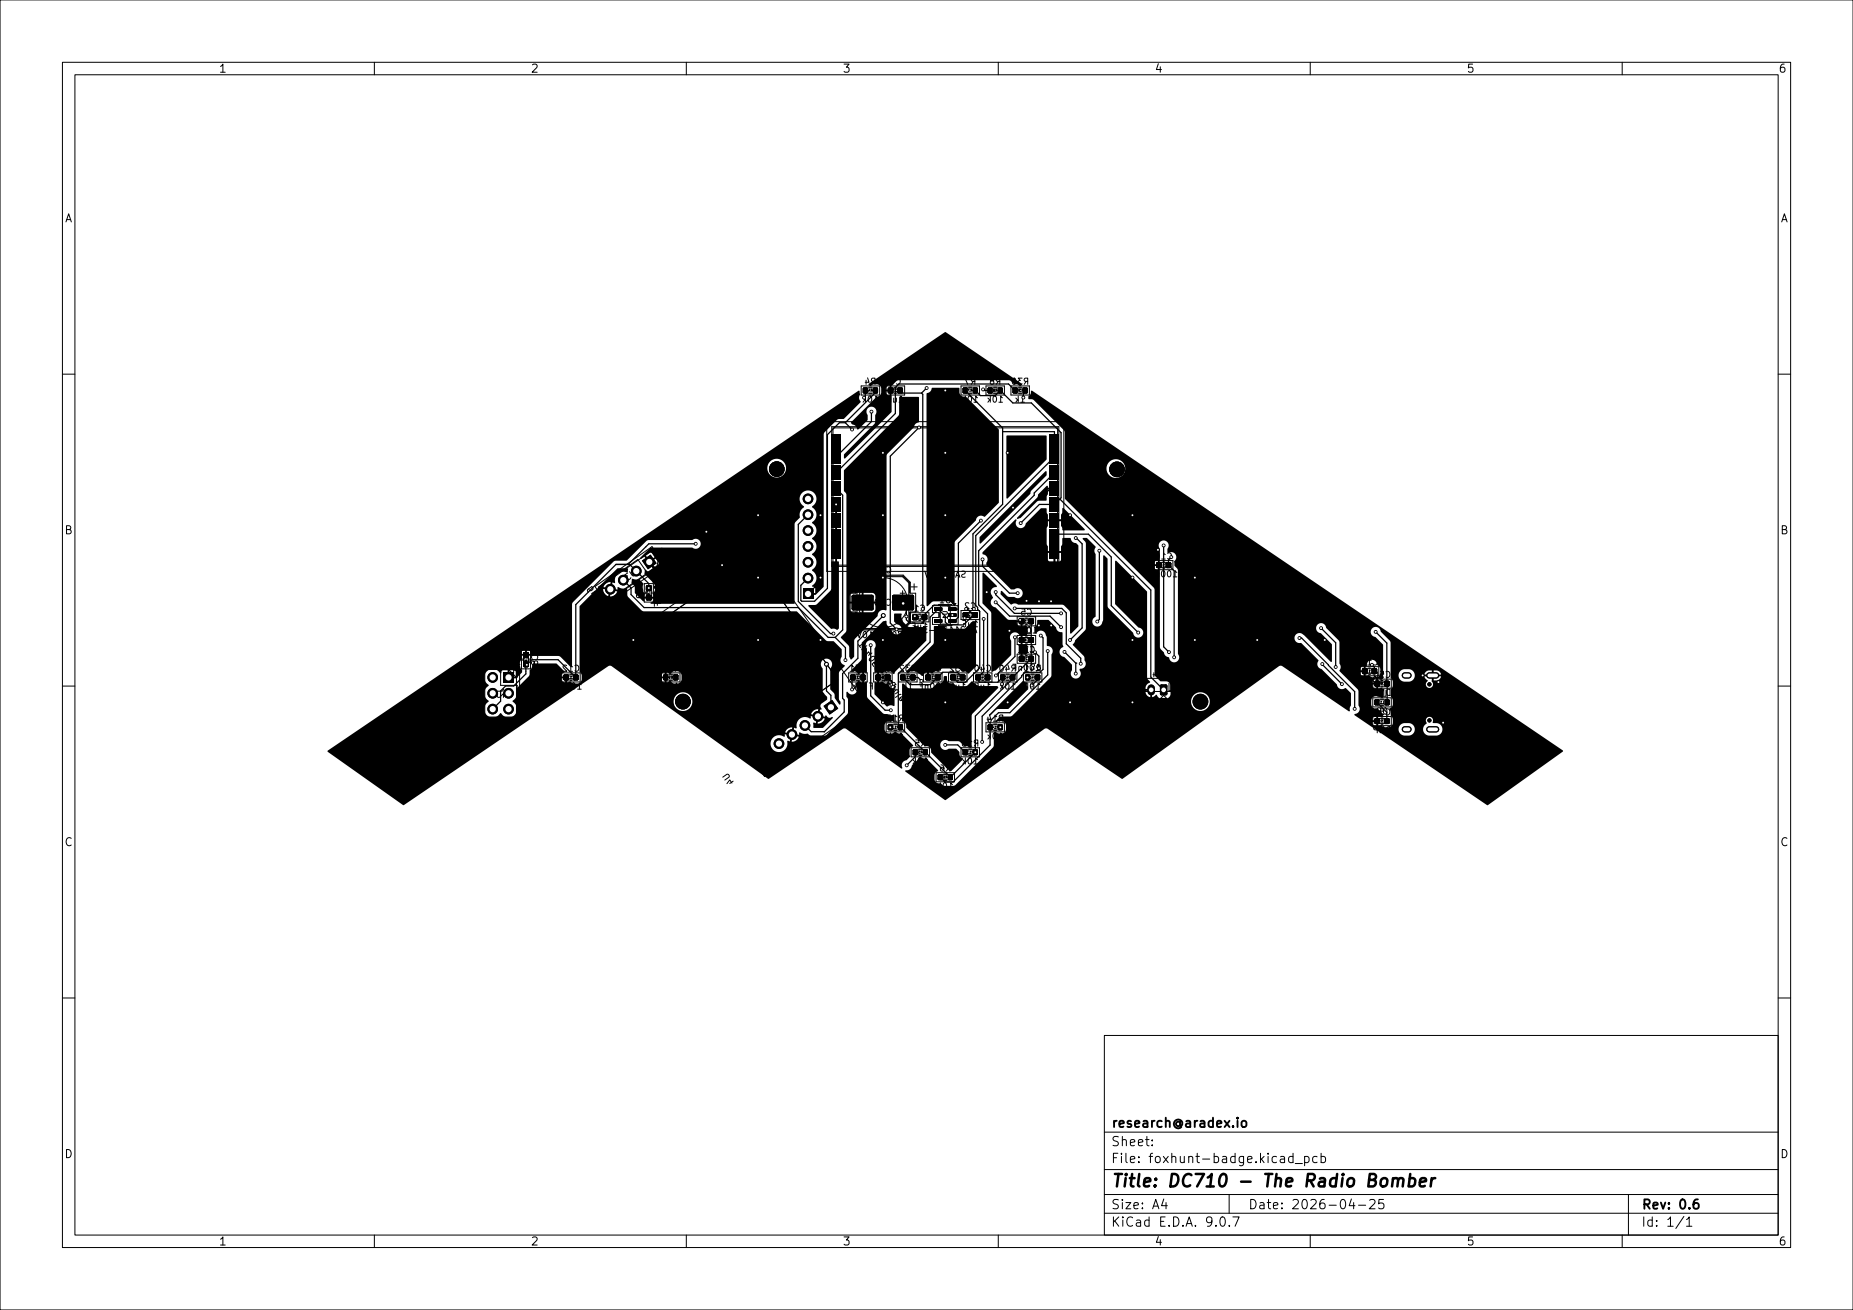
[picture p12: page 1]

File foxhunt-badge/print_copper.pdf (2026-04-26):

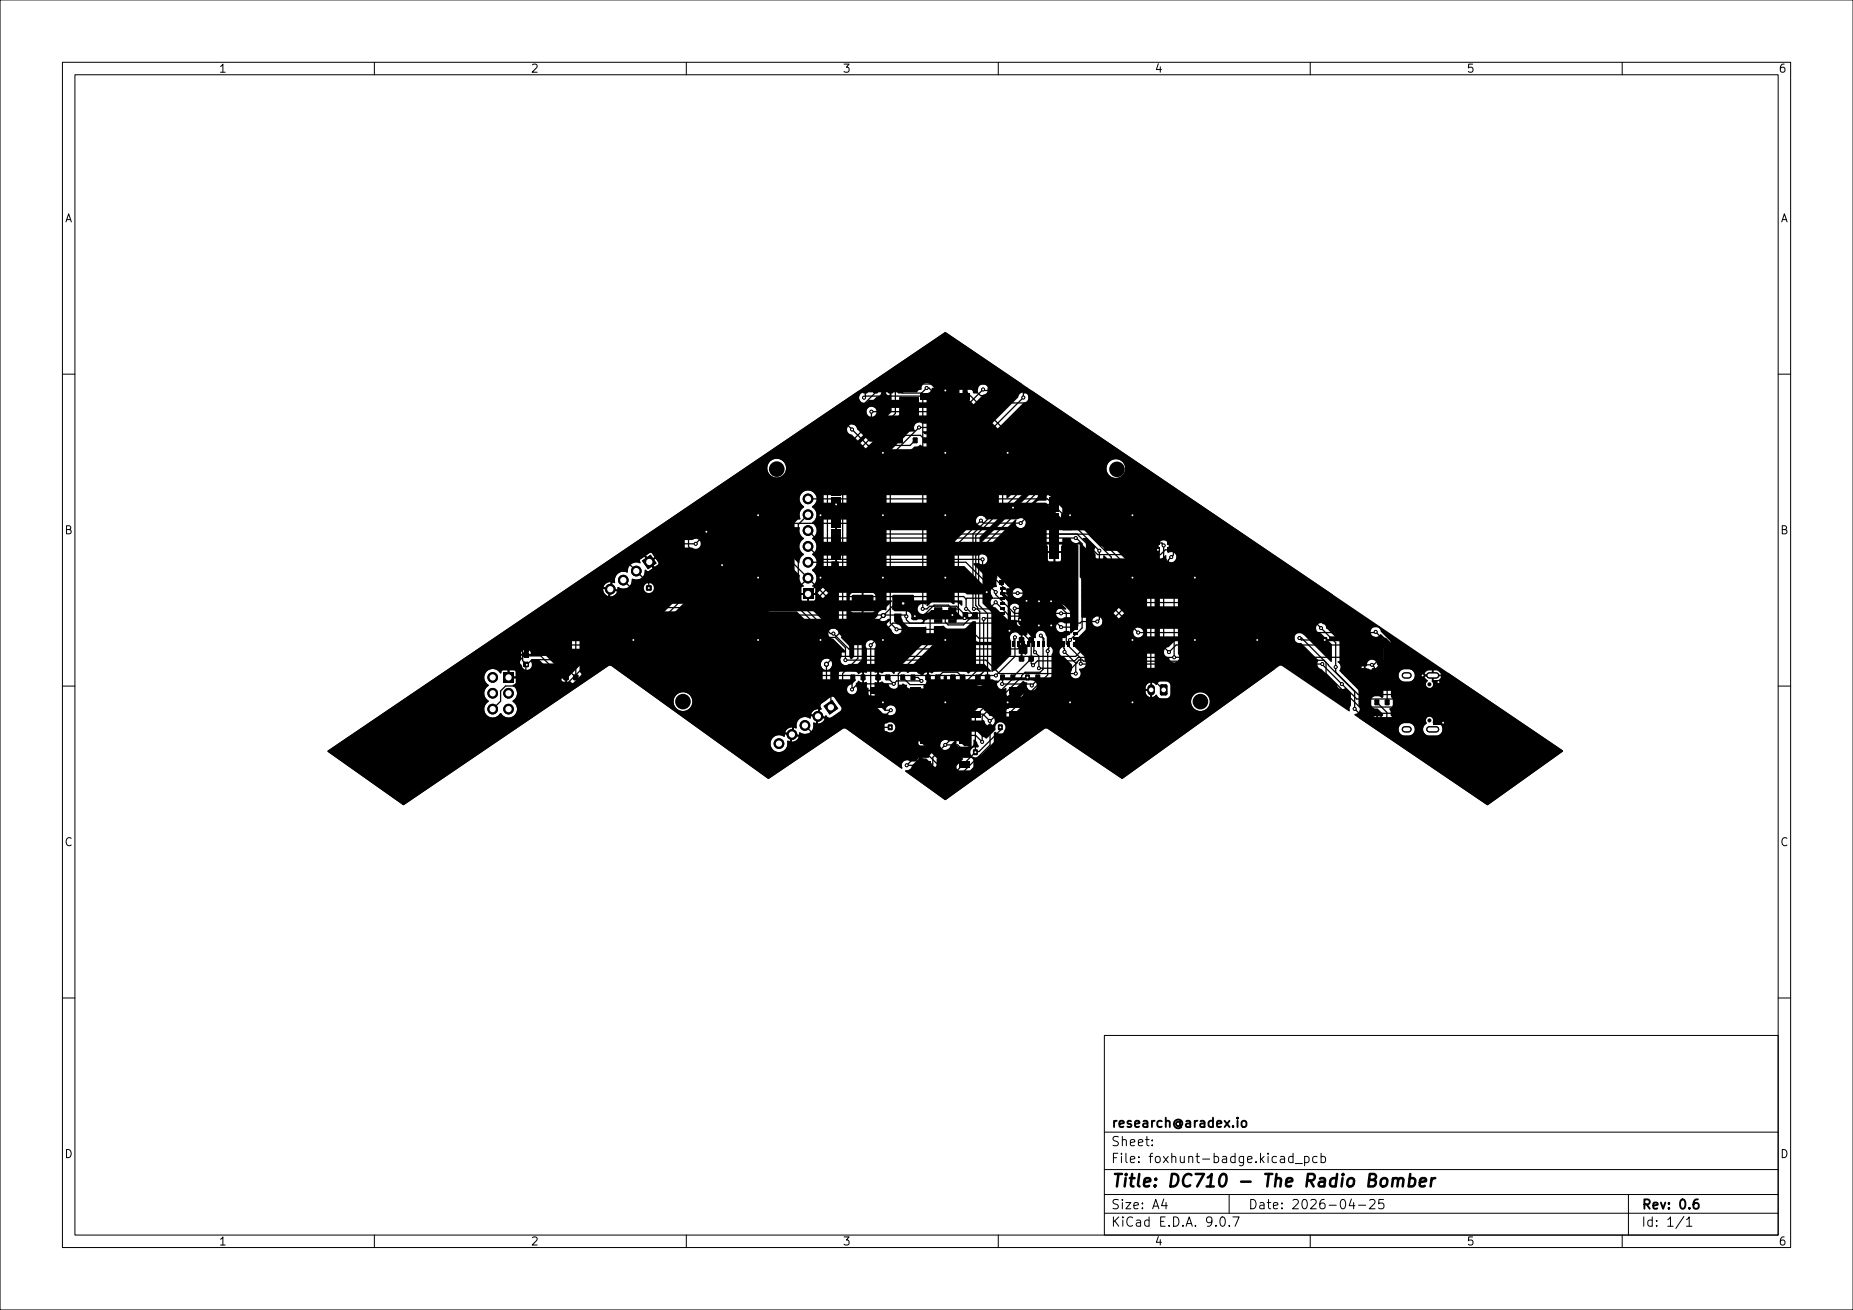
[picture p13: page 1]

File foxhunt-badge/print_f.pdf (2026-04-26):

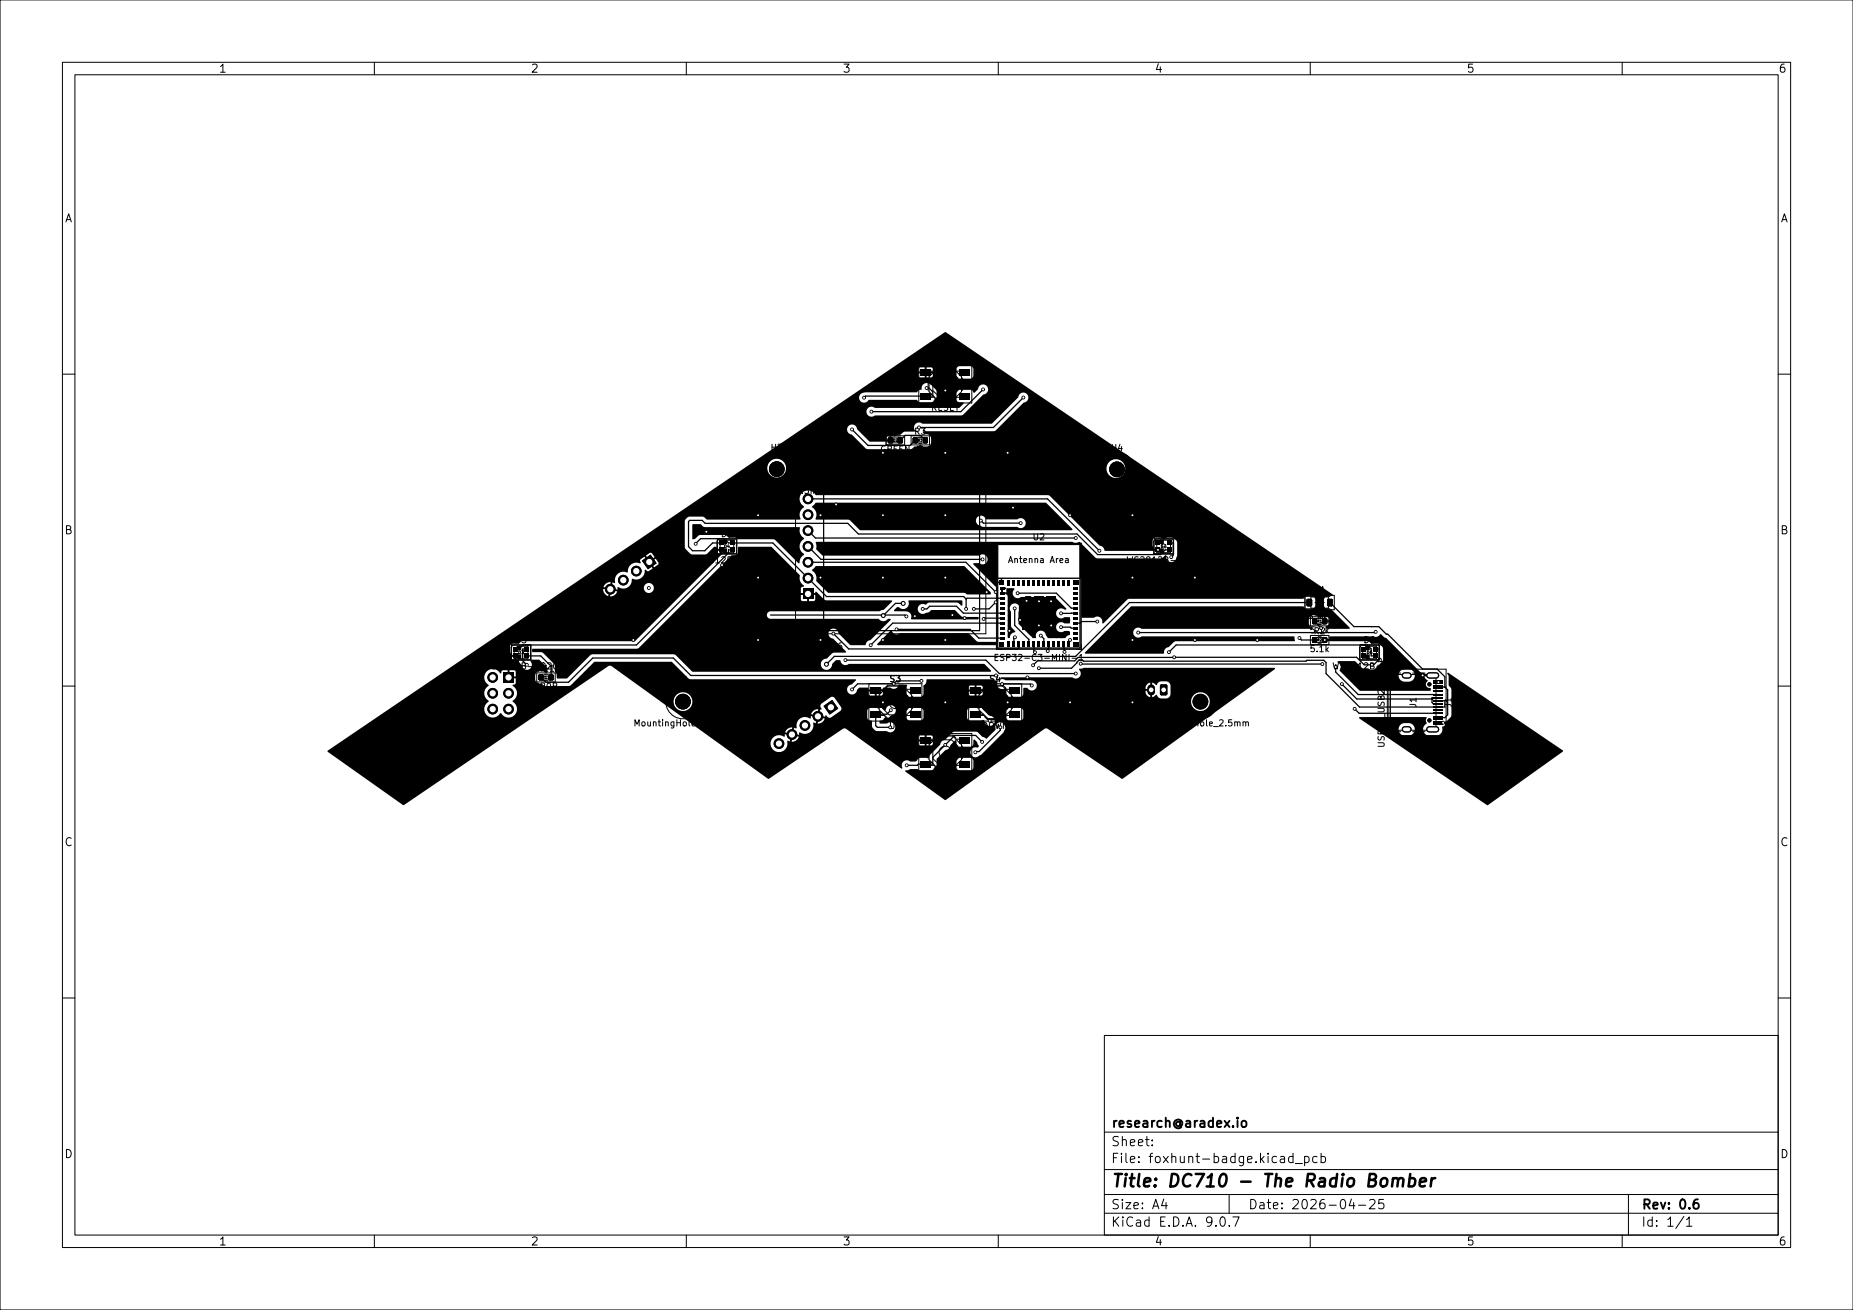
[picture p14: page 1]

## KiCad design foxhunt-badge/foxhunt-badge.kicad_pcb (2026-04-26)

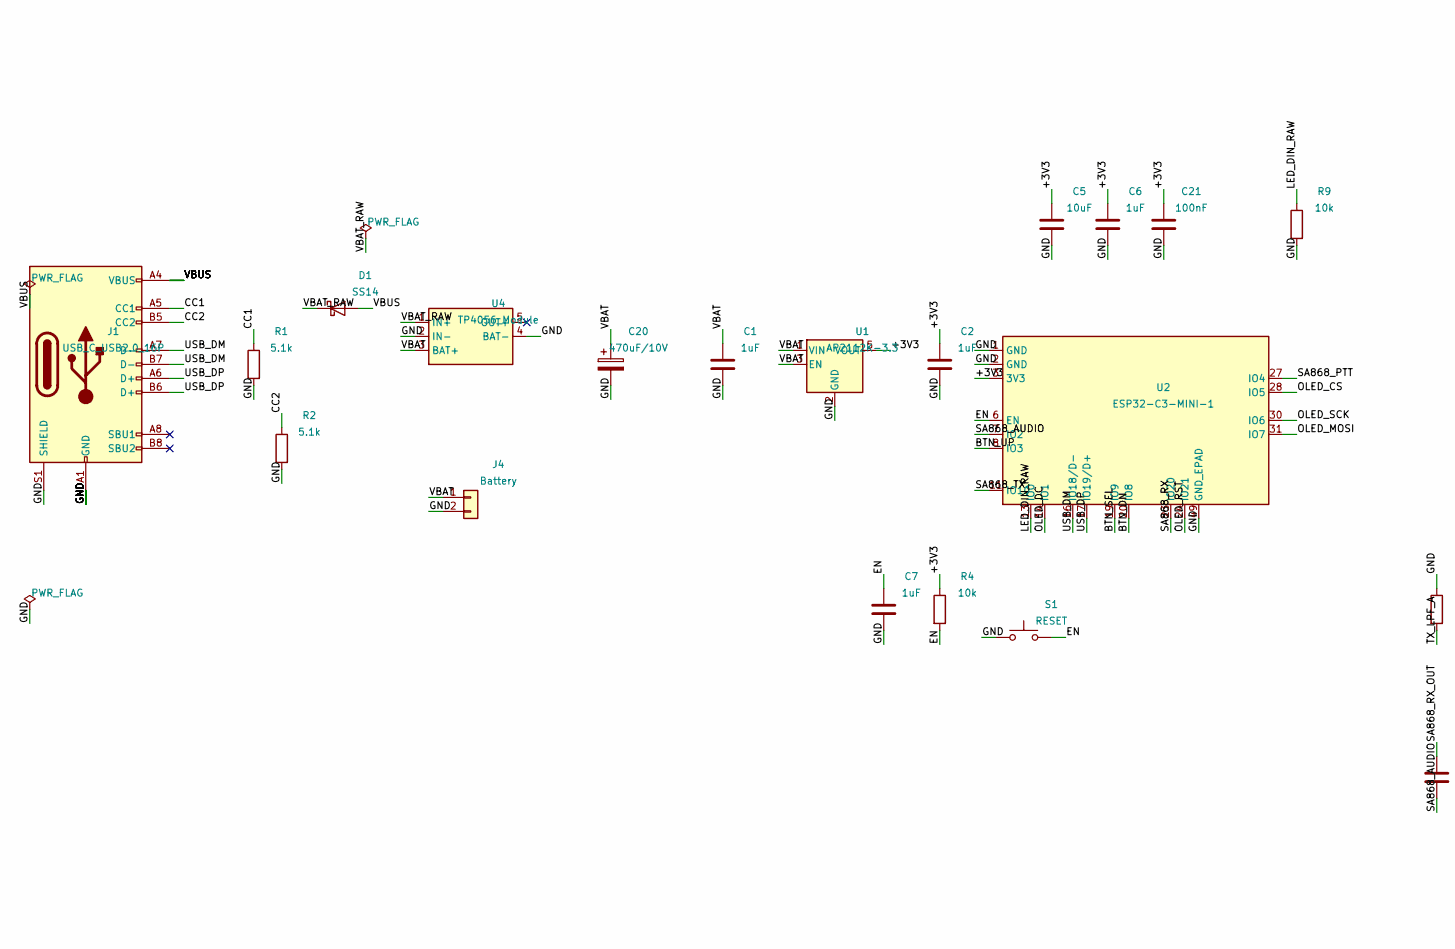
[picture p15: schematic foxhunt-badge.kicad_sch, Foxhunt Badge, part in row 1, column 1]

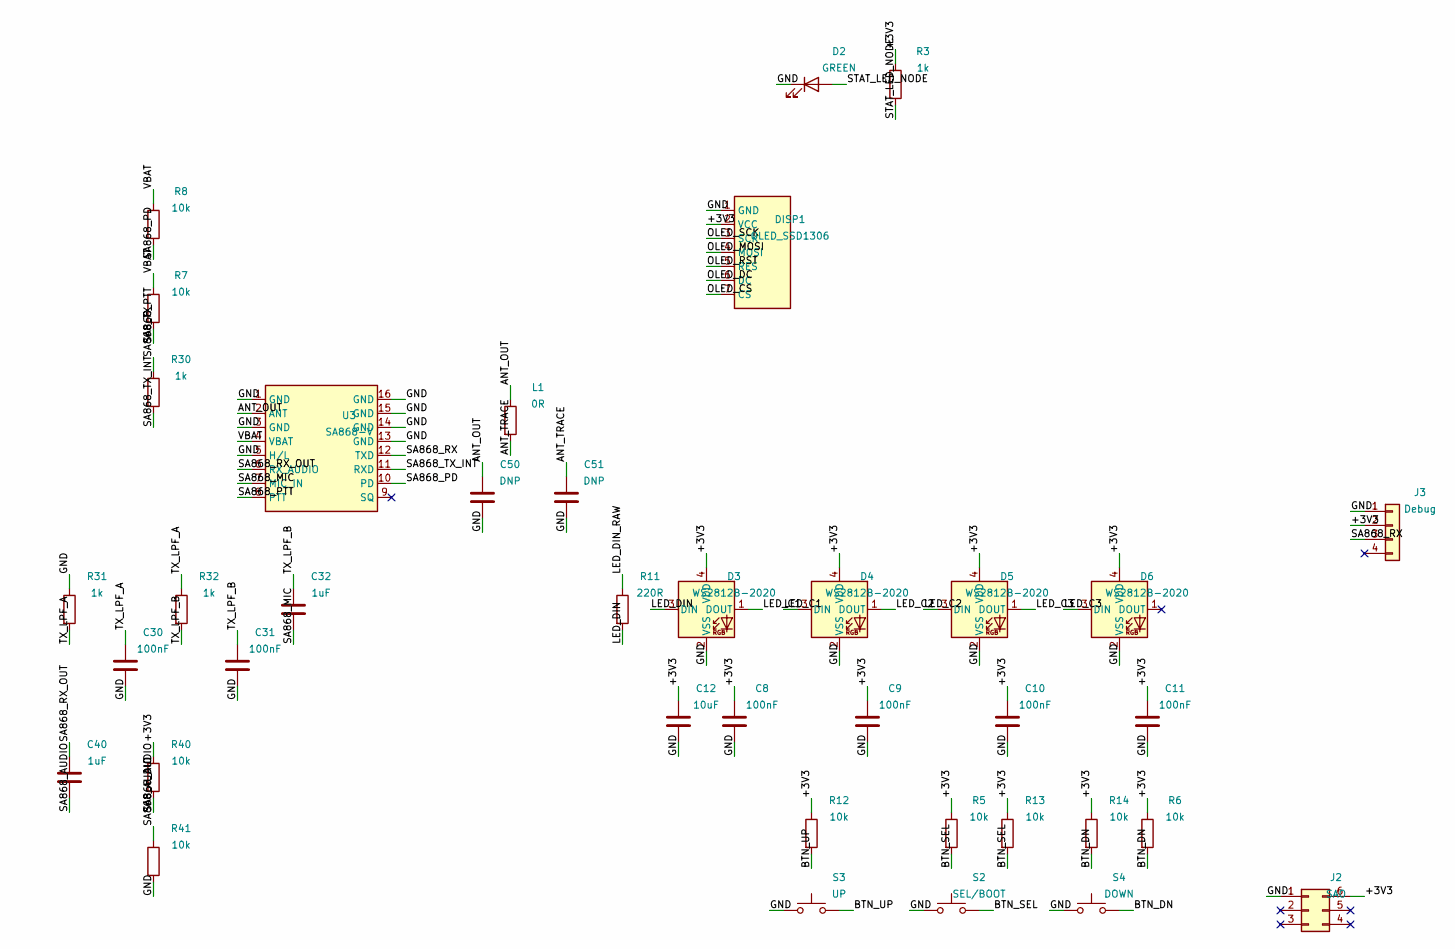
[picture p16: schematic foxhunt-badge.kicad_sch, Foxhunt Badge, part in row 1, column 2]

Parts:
C1, C2, C6, C7, C32, C40: 1uF; C_0603_1608Metric
C5, C12: 10uF; C_0603_1608Metric
C8, C9, C10, C11, C21, C30, C31: 100nF; C_0603_1608Metric
C20: 470uF/10V; CP_Elec_8x10
C50, C51: DNP; C_0603_1608Metric
D1: SS14; D_SOD-123
D2: GREEN; LED_0603_1608Metric
D3, D4, D5, D6: WS2812B-2020; LED_WS2812B-2020_PLCC4_2.0x2.0mm
DISP1: OLED_SSD1306; OLED_SSD1306_128x64_7P
J1: USB_C_USB2.0_16P; USB_C_Receptacle_HRO_TYPE-C-31-M-12
J2: SAO; PinHeader_2x03_P2.54mm_Vertical
J3: Debug; PinHeader_1x04_P2.54mm_Vertical
J4: Battery; JST_PH_S2B-PH-K_1x02_P2.00mm_Horizontal
L1: 0R; R_0603_1608Metric
R1, R2: 5.1k; R_0603_1608Metric
R3, R30, R31, R32: 1k; R_0603_1608Metric
R4, R5, R6, R7, R8, R9, R12, R13, R14, R40, R41: 10k; R_0603_1608Metric
R11: 220R; R_0603_1608Metric
S1: RESET; SW_SPST_TL3342
S2: SEL/BOOT; SW_SPST_TL3342
S3: UP; SW_SPST_TL3342
S4: DOWN; SW_SPST_TL3342
U1: AP2112K-3.3; SOT-23-5
U2: ESP32-C3-MINI-1
U3: SA868-V; SA868
U4: TP4056_Module

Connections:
+3V3: C2.1, C5.1, C6.1, C8.1, C9.1, C10.1, C11.1, C12.1, C21.1, D3.4 (VDD), D4.4 (VDD), D5.4 (VDD), D6.4 (VDD), DISP1.2 (VCC), J2.6, J3.2, R3.1, R4.1, R5.1, R6.1, R12.1, R13.1, R14.1, R40.1, U1.5 (VOUT), U2.3 (3V3)
ANT_OUT: C50.1, L1.1, U3.2 (ANT)
ANT_TRACE: C51.1, L1.2
BTN_DN: R6.2, R14.2, S4.2, U2.20 (IO8)
BTN_SEL: R5.2, R13.2, S2.2, U2.19 (IO9)
BTN_UP: R12.2, S3.2, U2.8 (IO3)
CC1: J1.A5 (CC1), R1.1
CC2: J1.B5 (CC2), R2.1
EN: C7.1, R4.2, S1.2, U2.6 (EN)
GND: C1.2, C2.2, C5.2, C6.2, C7.2, C8.2, C9.2, C10.2, C11.2, C12.2, C20.2, C21.2, C30.2, C31.2, C50.2, C51.2, D2.1 (K), D3.2 (VSS), D4.2 (VSS), D5.2 (VSS), D6.2 (VSS), DISP1.1 (GND), J1.A1 (GND), J1.A12 (GND), J1.B1 (GND), J1.B12 (GND), J1.S1 (SHIELD), J2.1, J3.1, J3.4, J4.2, R1.2, R2.2, R9.2, R31.1, R41.2, S1.1, S2.1, S3.1, S4.1, U1.2 (GND), U2.1 (GND), U2.2 (GND), U2.49 (GND_EPAD), U3.1 (GND), U3.3 (GND), U3.5 (H/L), U3.13 (GND), U3.14 (GND), U3.15 (GND), U3.16 (GND), U4.2 (IN-), U4.4 (BAT-)
LED_C1: D3.1 (DOUT), D4.3 (DIN)
LED_C2: D4.1 (DOUT), D5.3 (DIN)
LED_C3: D5.1 (DOUT), D6.3 (DIN)
LED_DIN: D3.3 (DIN), R11.2
LED_DIN_RAW: R9.1, R11.1, U2.13 (IO0)
LED_END: D6.1 (DOUT)
OLED_CS: DISP1.7 (CS), U2.28 (IO5)
OLED_DC: DISP1.6 (DC), U2.14 (IO1)
OLED_MOSI: DISP1.4 (MOSI), U2.31 (IO7)
OLED_RST: DISP1.5 (RES), U2.24 (IO21)
OLED_SCK: DISP1.3 (SCK), U2.30 (IO6)
SA868_AUDIO: C40.2, R40.2, R41.1, U2.7 (IO2)
SA868_MIC: C32.2, U3.7 (MIC_IN)
SA868_PD: R8.2, U3.10 (PD)
SA868_PTT: R7.2, U2.27 (IO4), U3.8 (PTT)
SA868_RX: J3.3, U2.23 (IO20), U3.12 (TXD)
SA868_RX_OUT: C40.1, U3.6 (RX_AUDIO)
SA868_SQ: U3.9 (SQ)
SA868_TX: R30.1, U2.11 (IO10)
SA868_TX_INT: R30.2, U3.11 (RXD)
SAO_GPIO1: J2.3
SAO_GPIO2: J2.2
SAO_GPIO3: J2.5
SAO_GPIO4: J2.4
STAT_LED_NODE: D2.2 (A), R3.2
TX_LPF_A: C30.1, R31.2, R32.1
TX_LPF_B: C31.1, C32.1, R32.2
USB_DM: J1.A7 (D-), J1.B7 (D-), U2.16 (IO18/D-)
USB_DP: J1.A6 (D+), J1.B6 (D+), U2.17 (IO19/D+)
USB_OUT: U4.5 (OUT+)
VBAT: C1.1, C20.1, J4.1, R7.1, R8.1, U1.1 (VIN), U1.3 (EN), U3.4 (VBAT), U4.3 (BAT+)
VBAT_RAW: D1.1 (K), U4.1 (IN+)
VBUS: D1.2 (A), J1.A4 (VBUS), J1.A9 (VBUS), J1.B4 (VBUS), J1.B9 (VBUS)

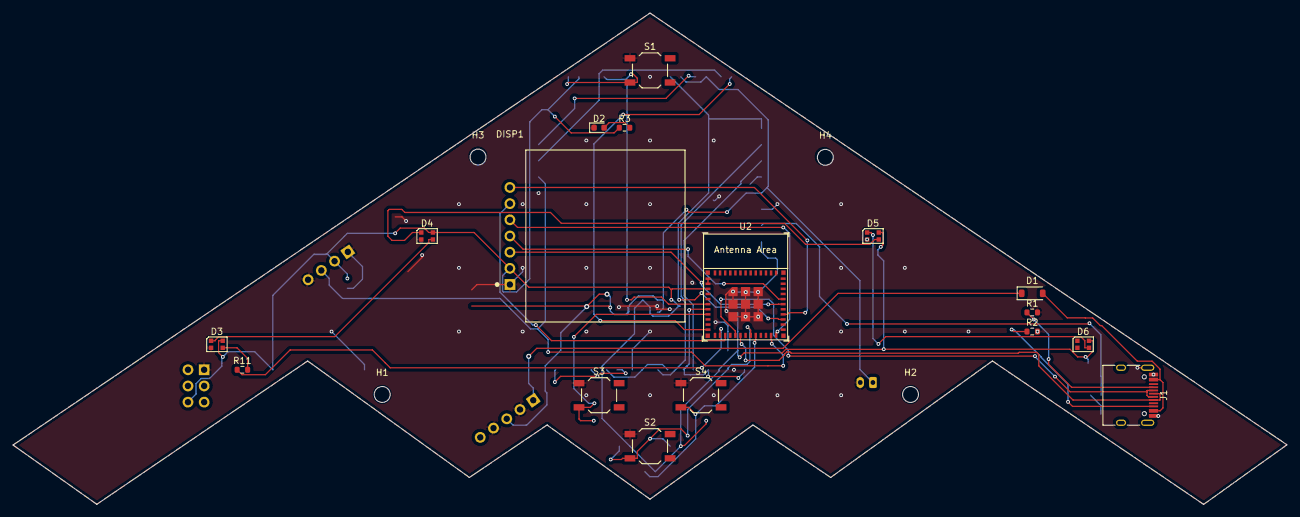
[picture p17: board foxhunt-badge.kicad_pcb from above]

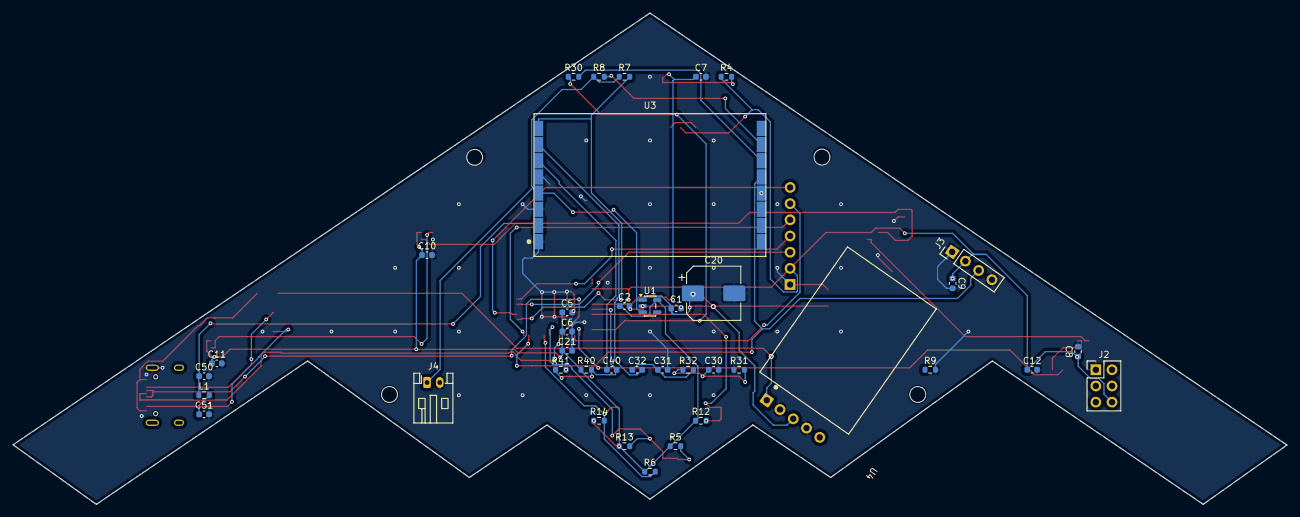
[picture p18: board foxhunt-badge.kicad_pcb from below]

Board: 2 copper layers, 200.0 x 77.1 mm, 60 parts (39 on the bottom side), 36 nets.

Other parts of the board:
H1, H2, H3, H4: MountingHole_2.5mm

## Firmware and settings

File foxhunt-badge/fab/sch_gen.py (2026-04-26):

#!/usr/bin/env python3
"""Generate foxhunt-badge.kicad_sch — clean ERC-passing KiCad 9 schematic.

Convention
----------
* Symbol pin coords stored in symbol files use Y-positive-up.
* Schematic uses Y-positive-down.  Hence:
    abs_pin_x = Cx + sym_pin_x
    abs_pin_y = Cy - sym_pin_y
* For each connected pin, draw a 2.54mm wire stub outward + label at the tip.
* Outward direction (in schematic) by pin angle: 0->(-1,0), 90->(0,1),
  180->(1,0), 270->(0,-1).

GPIO assignment (ESP32-C3-MINI-1, official Espressif footprint)
---------------------------------------------------------------
| Function    | GPIO | Pad |
|-------------|------|-----|
| GND         | -    |  1  |
| GND         | -    |  2  |
| 3V3         | -    |  3  |
| EN          | -    |  6  |
| AUDIO ADC   | 2    |  7  |
| BTN_UP      | 3    |  8  |
| SA868_TX    | 10   | 11  |
| WS2812 DIN  | 0    | 13  |
| OLED_DC     | 1    | 14  |
| USB_DM      | 18   | 16  |
| USB_DP      | 19   | 17  |
| BTN_SEL     | 9    | 19  |
| BTN_DN      | 8    | 20  |
| SA868_RX    | 20   | 23  |
| OLED_RST    | 21   | 24  |
| SA868_PTT   | 4    | 27  |
| OLED_CS     | 5    | 28  |
| OLED_SCK    | 6    | 30  |
| OLED_MOSI   | 7    | 31  |
| GND (EPAD)  | -    | 49  |
"""
from __future__ import annotations
from pathlib import Path
import re
import sys
import uuid

ROOT = Path(__file__).parent.parent
OUT_PATH = ROOT / "foxhunt-badge.kicad_sch"
STOCK = Path("/usr/share/kicad/symbols")
PROJECT_LIB = ROOT / "lib" / "foxhunt.kicad_sym"

sys.path.insert(0, str(Path(__file__).parent))
import lib_gen as LG  # type: ignore


GRID = 1.27
STUB = 2.54


def U(): return str(uuid.uuid4())
def snap(v): return round(v / GRID) * GRID
def C(x, y): return (snap(x), snap(y))


# ---------------------------------------------------------------------------
# Slurp library symbols (with extends)
# ---------------------------------------------------------------------------
def slurp_symbol(libpath: Path, name: str) -> str:
    text = libpath.read_text()
    m = re.search(rf'\n\s+\(symbol "{re.escape(name)}"', text)
    if not m:
        raise RuntimeError(f"symbol {name!r} not in {libpath}")
    start = m.start() + 1
    # advance to opening paren
    while text[start] in ' \t':
        start += 1
    depth = 0
    for i in range(start, len(text)):
        c = text[i]
        if c == "(":
            depth += 1
        elif c == ")":
            depth -= 1
            if depth == 0:
                return text[start : i + 1]
    raise RuntimeError("unterminated symbol")


def slurp_with_extends(libpath: Path, name: str, accum: dict[str, str]):
    if name in accum:
        return
    blk = slurp_symbol(libpath, name)
    accum[name] = blk
    m = re.search(r'\(extends "([^"]+)"', blk)
    if m:
        slurp_with_extends(libpath, m.group(1), accum)


def _scan_subblocks(blk: str, head_re: str):
    """Yield (start, end) byte offsets of each top-level (X ...) subblock
    inside a (symbol "..." ...) wrapper, where head_re is the inner head
    pattern (e.g., r'\\(property "').  Walk balanced parens."""
    n = len(blk)
    # Find inside of outer parens
    i = blk.index("(") + 1
    while i < n:
        m = re.search(head_re, blk[i:])
        if not m:
            return
        start = i + m.start()
        depth = 0
        for j in range(start, n):
            c = blk[j]
            if c == "(":
                depth += 1
            elif c == ")":
                depth -= 1
                if depth == 0:
                    yield start, j + 1
                    i = j + 1
                    break
        else:
            return


def flatten_extends(libpath: Path, name: str) -> str:
    """If `name` is a derived symbol (has extends), inline its base's body
    geometry under the derived name and drop the extends directive.  Returns
    a single self-contained (symbol "<name>" ...) block."""
    blk = slurp_symbol(libpath, name)
    m = re.search(r'\(extends "([^"]+)"\s*\)', blk)
    if not m:
        return blk

    # Walk chain to base
    base_name = m.group(1)
    base_blk = flatten_extends(libpath, base_name)

    # Strip derived's (extends ...) line
    derived_no_ext = re.sub(r'\(extends "[^"]+"\s*\)\s*\n?', '', blk, count=1)

    # Pull base's body subblocks (ones we want to inherit):
    #   pin_numbers, pin_names, exclude_from_sim, in_bom, on_board,
    #   power, (symbol "<base>_X_Y" ...) units
    inherit_heads = [
        r'\(pin_numbers',
        r'\(pin_names',
        r'\(exclude_from_sim',
        r'\(in_bom',
        r'\(on_board',
        r'\(power\b',
        r'\(symbol "',  # body unit blocks
    ]
    inherited_parts: list[str] = []
    for head in inherit_heads:
        for s, e in _scan_subblocks(base_blk, head):
            inherited_parts.append(base_blk[s:e])

    # Rename body unit blocks: "<base_name>_X_Y" -> "<name>_X_Y"
    fixed_parts = []
    for part in inherited_parts:
        part = re.sub(rf'\(symbol "{re.escape(base_name)}_',
                      f'(symbol "{name}_', part)
        fixed_parts.append(part)

    # Insert inherited parts before the closing ')' of the derived block.
    # First, find the position of the LAST closing paren of derived block
    last_paren = derived_no_ext.rfind(")")
    insert_text = "\n\t\t" + "\n\t\t".join(p.replace("\n", "\n\t\t")
                                           for p in fixed_parts) + "\n\t"
    return derived_no_ext[:last_paren] + insert_text + derived_no_ext[last_paren:]


# ---------------------------------------------------------------------------
# Pin-coord registry (symbol-local, Y-positive-up)
# ---------------------------------------------------------------------------
PIN_COORDS = {
    "Device:R":       {"1": (0, 3.81, 270, "passive"),
                       "2": (0, -3.81, 90, "passive")},
    "Device:C":       {"1": (0, 3.81, 270, "passive"),
                       "2": (0, -3.81, 90, "passive")},
    "Device:C_Polarized":      {"1": (0, 3.81, 270, "passive"),
                       "2": (0, -3.81, 90, "passive")},
    "Device:LED":     {"1": (-3.81, 0, 0,   "passive"),
                       "2": ( 3.81, 0, 180, "passive")},
    "Diode:SS14":     {"1": (-3.81, 0, 0,   "passive"),
                       "2": ( 3.81, 0, 180, "passive")},
    "Switch:SW_Push": {"1": (-5.08, 0, 0,   "passive"),
                       "2": ( 5.08, 0, 180, "passive")},
    "Regulator_Linear:AP2112K-3.3": {
        "1": (-7.62,  2.54, 0,   "power_in"),
        "2": ( 0,    -7.62, 90,  "power_in"),
        "3": (-7.62, -2.54, 0,   "input"),
        "4": ( 7.62, -2.54, 180, "no_connect"),
        "5": ( 7.62,  2.54, 180, "power_out"),
    },
    "LED:WS2812B-2020": {
        "1": ( 7.62,  0,    180, "output"),
        "2": ( 0,    -7.62, 90,  "power_in"),
        "3": (-7.62,  0,    0,   "input"),
        "4": ( 0,     7.62, 270, "power_in"),
    },
    "Connector_Generic:Conn_01x02": {
        "1": (-5.08,  0,    0, "passive"),
        "2": (-5.08, -2.54, 0, "passive"),
    },
    "Connector_Generic:Conn_01x04": {
        "1": (-5.08,  2.54, 0, "passive"),
        "2": (-5.08,  0,    0, "passive"),
        "3": (-5.08, -2.54, 0, "passive"),
        "4": (-5.08, -5.08, 0, "passive"),
    },
    "Connector_Generic:Conn_01x07": {
        "1": (-5.08,  7.62, 0, "passive"),
        "2": (-5.08,  5.08, 0, "passive"),
        "3": (-5.08,  2.54, 0, "passive"),
        "4": (-5.08,  0,    0, "passive"),
        "5": (-5.08, -2.54, 0, "passive"),
        "6": (-5.08, -5.08, 0, "passive"),
        "7": (-5.08, -7.62, 0, "passive"),
    },
    "Connector_Generic:Conn_02x03_Counter_Clockwise": {
        "1": (-5.08,  2.54, 0,   "passive"),
        "2": (-5.08,  0,    0,   "passive"),
        "3": (-5.08, -2.54, 0,   "passive"),
        "6": ( 7.62,  2.54, 180, "passive"),
        "5": ( 7.62,  0,    180, "passive"),
        "4": ( 7.62, -2.54, 180, "passive"),
    },
    # USB-C 16P (USB2.0): pin coords from /usr/share/kicad/symbols/Connector.kicad_sym
    "Connector:USB_C_Receptacle_USB2.0_16P": {
        "S1":  ( -7.62, -22.86, 90,  "passive"),
        "A1":  ( 0,     -22.86, 90,  "passive"),
        "A12": ( 0,     -22.86, 90,  "passive"),
        "B1":  ( 0,     -22.86, 90,  "passive"),
        "B12": ( 0,     -22.86, 90,  "passive"),
        "A4":  ( 15.24,  15.24, 180, "passive"),
        "B4":  ( 15.24,  15.24, 180, "passive"),
        "A9":  ( 15.24,  15.24, 180, "passive"),
        "B9":  ( 15.24,  15.24, 180, "passive"),
        "A5":  ( 15.24,  10.16, 180, "passive"),
        "B5":  ( 15.24,   7.62, 180, "passive"),
        "A6":  ( 15.24,   2.54, 180, "passive"),
        "B6":  ( 15.24,   2.54, 180, "passive"),
        "A7":  ( 15.24,   0,    180, "passive"),
        "B7":  ( 15.24,   0,    180, "passive"),
        "A8":  ( 15.24,  -5.08, 180, "passive"),
        "B8":  ( 15.24,  -7.62, 180, "passive"),
    },
    # Power flag-class symbols
    "power:+3V3":  {"1": (0, 0, 90, "power_in")},
    "power:VBUS":  {"1": (0, 0, 90, "power_in")},
    "power:VBAT":  {"1": (0, 0, 90, "power_in")},
    "power:GND":   {"1": (0, 0, 270, "power_in")},
    "power:PWR_FLAG": {"1": (0, 0, 90, "power_out")},
}


def custom_pins(pins_l, pins_r, pins_b=None, body_w=20.32, pin_len=2.54):
    pins_b = pins_b or []
    body_h = max(len(pins_l), len(pins_r)) * 2.54 + 2.54
    if pins_b:
        body_w = max(body_w, len(pins_b) * 2.54 + 2.54)
    half_w, half_h = body_w / 2, body_h / 2
    out = {}
    for i, p in enumerate(pins_l):
        out[p["num"]] = (-half_w - pin_len,
                         half_h - 2.54 * (i + 1),
                         0, p.get("etype", "passive"))
    for i, p in enumerate(pins_r):
        out[p["num"]] = (half_w + pin_len,
                         half_h - 2.54 * (i + 1),
                         180, p.get("etype", "passive"))
    for i, p in enumerate(pins_b):
        out[p["num"]] = (-half_w + 2.54 * (i + 1),
                         -half_h - pin_len,
                         90, p.get("etype", "passive"))
    return out


PIN_COORDS["foxhunt:ESP32-C3-MINI-1"] = custom_pins(
    LG.ESP32_PINS_LEFT, LG.ESP32_PINS_RIGHT, LG.ESP32_PINS_BOTTOM, body_w=22.86)
PIN_COORDS["foxhunt:SA868"] = custom_pins(
    LG.SA868_PINS_LEFT, LG.SA868_PINS_RIGHT, body_w=20.32)
PIN_COORDS["foxhunt:TP4056_Module"] = custom_pins(
    LG.TP4056_PINS_LEFT, LG.TP4056_PINS_RIGHT, body_w=15.24)
PIN_COORDS["foxhunt:OLED_SSD1306"] = custom_pins(
    LG.OLED_PINS_LEFT, [], body_w=10.16)


def extract_pins_from_block(symbol_block: str) -> dict[str, tuple[float, float, int, str]]:
    """Walk every (pin TYPE line (at X Y A) ... (number "N") ...) inside a
    flattened (symbol "..." ...) block and return {num: (x, y, angle, type)}.
    """
    out: dict[str, tuple[float, float, int, str]] = {}
    for m in re.finditer(
        r'\(pin\s+(\w+)\s+\w+\s*\(at\s+([\d\.\-]+)\s+([\d\.\-]+)\s+(\d+)\)',
        symbol_block, re.S
    ):
        ptype = m.group(1)
        x, y, ang = float(m.group(2)), float(m.group(3)), int(m.group(4))
        # Find the (number "N") that follows this pin
        rest = symbol_block[m.end():]
        nm = re.search(r'\(number "([^"]+)"', rest)
        if not nm:
            continue
        # Make sure the number is INSIDE this pin block (within first balanced
        # close).  Easiest heuristic: the (number ...) shouldn't span past the
        # next (pin start.
        next_pin = re.search(r'\(pin\s+\w+\s+\w+\s*\(at', rest)
        if next_pin and nm.start() > next_pin.start():
            continue
        out[nm.group(1)] = (x, y, ang, ptype)
    return out


def autoload_pin_coords():
    """Override hardcoded entries by parsing the actual library files.
    This ensures wire stub endpoints line up with the symbol's true pin
    positions in lib_symbols."""
    seen_libids = sorted({c["lib_id"] for c in COMPS})
    for libid in seen_libids:
        lib_part, sym_name = libid.split(":", 1)
        if lib_part == "foxhunt":
            libpath = PROJECT_LIB
        else:
            libpath = STOCK / f"{lib_part}.kicad_sym"
        flat = flatten_extends(libpath, sym_name)
        pins = extract_pins_from_block(flat)
        if pins:
            PIN_COORDS[libid] = pins  # always override


# `COMPS` is empty at this point — populate AFTER components are added.
def _compute_post_comps():
    """Call after all comp() calls — overrides stock symbol pin coords from
    the actual stock library files."""
    autoload_pin_coords()
    # Snap all coords to grid
    for libid, pins in PIN_COORDS.items():
        for num in list(pins.keys()):
            x, y, ang, et = pins[num]
            pins[num] = (snap(x), snap(y), ang, et)


# ---------------------------------------------------------------------------
# Outward direction lookup (schematic frame, Y-positive-down)
# ---------------------------------------------------------------------------
OUTWARD = {0: (-1, 0), 90: (0, 1), 180: (1, 0), 270: (0, -1)}


def abs_pin(c, pin_num):
    """Return (abs_x, abs_y, angle, etype) for a pin of placed component c."""
    libid = c["lib_id"]
    if libid not in PIN_COORDS:
        raise RuntimeError(f"missing pin coords for {libid}")
    if pin_num not in PIN_COORDS[libid]:
        raise RuntimeError(f"pin {pin_num} not in {libid}; have "
                           f"{sorted(PIN_COORDS[libid].keys())[:8]}")
    sx, sy, ang, et = PIN_COORDS[libid][pin_num]
    return (snap(c["x"] + sx), snap(c["y"] - sy), ang, et)


# ===========================================================================
# Components
# ===========================================================================
COMPS = []


def comp(ref, lib_id, value, footprint, x, y):
    px, py = C(x, y)
    COMPS.append(dict(ref=ref, lib_id=lib_id, value=value,
                      footprint=footprint, x=px, y=py, uuid=U()))


# Power flag drivers (each driver has a one-pin power_out at (x,y))
def pflag(ref, libid, x, y):
    px, py = C(x, y)
    COMPS.append(dict(ref=ref, lib_id=libid, value=libid.split(":")[-1],
                      footprint="", x=px, y=py, uuid=U(), is_power=True))


# --- Zone 1: USB-C input + Schottky + CC pulldowns ---
comp("J1", "Connector:USB_C_Receptacle_USB2.0_16P", "USB_C_USB2.0_16P",
     "Connector_USB:USB_C_Receptacle_HRO_TYPE-C-31-M-12", 60, 100)
comp("R1", "Device:R", "5.1k", "Resistor_SMD:R_0603_1608Metric", 90, 100)
comp("R2", "Device:R", "5.1k", "Resistor_SMD:R_0603_1608Metric", 95, 115)
comp("D1", "Diode:SS14", "SS14", "Diode_SMD:D_SOD-123", 105, 90)

# --- Zone 2: TP4056 + battery JST + 470uF bulk ---
comp("U4", "foxhunt:TP4056_Module", "TP4056_Module",
     "foxhunt:TP4056_Module", 130, 95)
comp("J4", "Connector_Generic:Conn_01x02", "Battery",
     "Connector_JST:JST_PH_S2B-PH-K_1x02_P2.00mm_Horizontal", 130, 125)
comp("C20", "Device:C_Polarized", "470uF/10V", "Capacitor_SMD:CP_Elec_8x10", 155, 100)

# --- Zone 3: AP2112K-3.3 LDO + decoupling ---
comp("C1", "Device:C", "1uF",  "Capacitor_SMD:C_0603_1608Metric", 175, 100)
comp("U1", "Regulator_Linear:AP2112K-3.3", "AP2112K-3.3",
     "Package_TO_SOT_SMD:SOT-23-5", 195, 100)
comp("C2", "Device:C", "1uF",  "Capacitor_SMD:C_0603_1608Metric", 215, 100)

# --- Zone 4: ESP32-C3-MINI-1 + decoupling + reset RC + strap pulls ---
comp("U2", "foxhunt:ESP32-C3-MINI-1", "ESP32-C3-MINI-1",
     "foxhunt:ESP32-C3-MINI-1", 250, 110)
comp("C5", "Device:C", "10uF", "Capacitor_SMD:C_0603_1608Metric", 235, 75)
comp("C6", "Device:C", "1uF",  "Capacitor_SMD:C_0603_1608Metric", 245, 75)
comp("C21", "Device:C", "100nF","Capacitor_SMD:C_0603_1608Metric", 255, 75)
comp("S1", "Switch:SW_Push", "RESET",
     "Button_Switch_SMD:SW_SPST_TL3342", 230, 150)
comp("R4", "Device:R", "10k", "Resistor_SMD:R_0603_1608Metric", 215, 145)
comp("C7", "Device:C", "1uF", "Capacitor_SMD:C_0603_1608Metric", 205, 145)

# --- Zone 5: SA868 + audio LPF + RX bias + antenna match + pulls ---
comp("U3", "foxhunt:SA868", "SA868-V", "foxhunt:SA868", 350, 115)
comp("R7", "Device:R", "10k", "Resistor_SMD:R_0603_1608Metric", 320, 90)
comp("R8", "Device:R", "10k", "Resistor_SMD:R_0603_1608Metric", 320, 75)
comp("R30","Device:R", "1k",  "Resistor_SMD:R_0603_1608Metric", 320, 105)
# Audio TX low-pass
comp("R31","Device:R", "1k",  "Resistor_SMD:R_0603_1608Metric", 305, 145)
comp("C30","Device:C", "100nF","Capacitor_SMD:C_0603_1608Metric", 315, 155)
comp("R32","Device:R", "1k",  "Resistor_SMD:R_0603_1608Metric", 325, 145)
comp("C31","Device:C", "100nF","Capacitor_SMD:C_0603_1608Metric", 335, 155)
comp("C32","Device:C", "1uF", "Capacitor_SMD:C_0603_1608Metric", 345, 145)
# Audio RX bias
comp("C40","Device:C", "1uF", "Capacitor_SMD:C_0603_1608Metric", 305, 175)
comp("R40","Device:R", "10k", "Resistor_SMD:R_0603_1608Metric", 320, 175)
comp("R41","Device:R", "10k", "Resistor_SMD:R_0603_1608Metric", 320, 190)
# Antenna match
comp("L1", "Device:R", "0R",  "Resistor_SMD:R_0603_1608Metric", 385, 110)
comp("C50","Device:C", "DNP", "Capacitor_SMD:C_0603_1608Metric", 380, 125)
comp("C51","Device:C", "DNP", "Capacitor_SMD:C_0603_1608Metric", 395, 125)

# --- Zone 6: OLED display + status LED ---
comp("DISP1", "foxhunt:OLED_SSD1306", "OLED_SSD1306",
     "foxhunt:OLED_SSD1306_128x64_7P", 430, 80)
comp("D2", "Device:LED", "GREEN", "LED_SMD:LED_0603_1608Metric", 440, 50)
comp("R3", "Device:R", "1k", "Resistor_SMD:R_0603_1608Metric", 455, 50)

# --- Zone 7: WS2812B chain + decoupling ---
comp("R11","Device:R", "220R", "Resistor_SMD:R_0603_1608Metric", 405, 145)
comp("D3", "LED:WS2812B-2020", "WS2812B-2020",
     "LED_SMD:LED_WS2812B-2020_PLCC4_2.0x2.0mm", 420, 145)
comp("D4", "LED:WS2812B-2020", "WS2812B-2020",
     "LED_SMD:LED_WS2812B-2020_PLCC4_2.0x2.0mm", 445, 145)
comp("D5", "LED:WS2812B-2020", "WS2812B-2020",
     "LED_SMD:LED_WS2812B-2020_PLCC4_2.0x2.0mm", 470, 145)
comp("D6", "LED:WS2812B-2020", "WS2812B-2020",
     "LED_SMD:LED_WS2812B-2020_PLCC4_2.0x2.0mm", 495, 145)
comp("C12","Device:C", "10uF", "Capacitor_SMD:C_0603_1608Metric", 415, 165)
comp("C8", "Device:C", "100nF","Capacitor_SMD:C_0603_1608Metric", 425, 165)
comp("C9", "Device:C", "100nF","Capacitor_SMD:C_0603_1608Metric", 450, 165)
comp("C10","Device:C", "100nF","Capacitor_SMD:C_0603_1608Metric", 475, 165)
comp("C11","Device:C", "100nF","Capacitor_SMD:C_0603_1608Metric", 500, 165)

# --- Zone 8: Buttons + pull-ups ---
comp("S2", "Switch:SW_Push", "SEL/BOOT",
     "Button_Switch_SMD:SW_SPST_TL3342", 465, 200)
comp("S3", "Switch:SW_Push", "UP",
     "Button_Switch_SMD:SW_SPST_TL3342", 440, 200)
comp("S4", "Switch:SW_Push", "DOWN",
     "Button_Switch_SMD:SW_SPST_TL3342", 490, 200)
comp("R12","Device:R", "10k", "Resistor_SMD:R_0603_1608Metric", 440, 185)
comp("R5", "Device:R", "10k", "Resistor_SMD:R_0603_1608Metric", 465, 185)
comp("R13","Device:R", "10k", "Resistor_SMD:R_0603_1608Metric", 475, 185)
comp("R14","Device:R", "10k", "Resistor_SMD:R_0603_1608Metric", 490, 185)
comp("R6", "Device:R", "10k", "Resistor_SMD:R_0603_1608Metric", 500, 185)
# GPIO0 (LED chain) keep-low-at-boot pull-down
comp("R9", "Device:R", "10k", "Resistor_SMD:R_0603_1608Metric", 280, 75)

# --- Zone 9: Headers ---
comp("J2", "Connector_Generic:Conn_02x03_Counter_Clockwise", "SAO",
     "Connector_PinHeader_2.54mm:PinHeader_2x03_P2.54mm_Vertical", 530, 200)
comp("J3", "Connector_Generic:Conn_01x04", "Debug",
     "Connector_PinHeader_2.54mm:PinHeader_1x04_P2.54mm_Vertical", 545, 130)

# --- Power flag drivers ---
pflag("#FLG_VBUS",     "power:PWR_FLAG", 50, 88)
pflag("#FLG_VBAT_RAW", "power:PWR_FLAG", 110, 78)
pflag("#FLG_GND",      "power:PWR_FLAG", 50, 145)
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

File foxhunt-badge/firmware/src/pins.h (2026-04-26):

// pins.h -- Foxhunt Badge ESP32-C3 pin map
// Single source of truth. Change here, propagate everywhere.
#pragma once

#include <Arduino.h>

// ---- LED chain ----
constexpr uint8_t PIN_LED_DIN   = 0;
constexpr uint8_t NUM_LEDS      = 4;

// ---- OLED (SPI) ----
constexpr uint8_t PIN_OLED_DC   = 1;
constexpr uint8_t PIN_OLED_CS   = 5;
constexpr uint8_t PIN_OLED_SCK  = 6;
constexpr uint8_t PIN_OLED_MOSI = 7;
constexpr uint8_t PIN_OLED_RST  = 8;

// ---- Buttons (active low, internal pullups OK on non-strap pins) ----
constexpr uint8_t PIN_BTN_UP    = 3;
constexpr uint8_t PIN_BTN_SEL   = 9;   // doubles as BOOT
constexpr uint8_t PIN_BTN_DN    = 17;

// ---- SA868 radio ----
constexpr uint8_t PIN_SA868_PTT      = 10;  // active low
constexpr uint8_t PIN_SA868_UART_RX  = 11;  // ESP RX <- module TX
constexpr uint8_t PIN_SA868_UART_TX  = 12;  // ESP TX -> module RX
constexpr uint8_t PIN_SA868_PD       = 13;  // active low (low = sleep)
constexpr uint8_t PIN_SA868_MIC_PWM  = 15;  // PWM -> RC LPF -> MIC_IN
constexpr uint8_t PIN_SA868_RX_AUDIO = 16;  // ADC <- RX_OUT (AC-coupled)

// ---- Debug UART ----
constexpr uint8_t PIN_DBG_RX = 20;
constexpr uint8_t PIN_DBG_TX = 21;

// ---- Other ----
constexpr uint32_t MIC_PWM_FREQ_HZ   = 80000;   // out of audio band
constexpr uint8_t  MIC_PWM_RES_BITS  = 8;
constexpr uint8_t  MIC_PWM_CHANNEL   = 0;

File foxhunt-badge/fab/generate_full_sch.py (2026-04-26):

"""
Generate foxhunt-badge.kicad_sch -- a complete, single-page schematic
with every component placed and every pin labeled with its net name.

Approach: label-stub style. For each component pin, draw a short wire
stub outward and place a label at the end. KiCad's ERC connects matching
labels automatically. This is a standard schematic style for dense
designs and is fully ERC-compliant.

Layout (A3 sheet, 420 x 297 mm):
  +------------------------------------+
  | TITLE BLOCK                        |
  | POWER ZONE      |   MCU ZONE       |
  | (USB-C, TP4056, |   (ESP32-C3,     |
  |  LDO, batt)     |    decoupling,   |
  |                 |    debug)        |
  |-----------------+------------------|
  | RADIO ZONE      |   UI ZONE        |
  | (SA868, audio,  |   (OLED, LEDs,   |
  |  antenna)       |    buttons, SAO) |
  +------------------------------------+
"""

import hashlib
import sys
from pathlib import Path

sys.path.insert(0, str(Path(__file__).parent))
from sch_lib_symbols import all_lib_symbols, ESP32_C3_PINS, SA868_PINS, AP2112_PINS, WS2812_PINS, USBC_PINS, SAO_PINS

KICAD_SCH_VERSION = 20231120
PROJECT_DIR = Path(__file__).parent.parent


def uuid_from(seed: str) -> str:
    h = hashlib.md5(seed.encode()).hexdigest()
    return f"{h[0:8]}-{h[8:12]}-{h[12:16]}-{h[16:20]}-{h[20:32]}"


# ---------------------------------------------------------------------------
# Pin geometry - replicate IC body geometry from sch_lib_symbols.make_ic_symbol
# ---------------------------------------------------------------------------

def compute_pin_abs_pos(comp_pos, comp_pin_data, body_w, body_h):
    """Replicate make_ic_symbol's pin positioning math.

    Returns (abs_x, abs_y, orient_deg, stub_dx, stub_dy) where stub is
    the direction the wire stub should go (outward from the body).
    """
    half_w = body_w / 2
    half_h = body_h / 2
    pin_len = 2.54
    side = comp_pin_data['side']

    if side == 'L':
        rel_x = -half_w - pin_len
        rel_y = half_h - comp_pin_data['pos_mm']
        stub_dx = -2.54
        stub_dy = 0
    elif side == 'R':
        rel_x = half_w + pin_len
        rel_y = half_h - comp_pin_data['pos_mm']
        stub_dx = 2.54
        stub_dy = 0
    elif side == 'T':
        rel_x = -half_w + comp_pin_data['pos_mm']
        rel_y = half_h + pin_len
        stub_dx = 0
        stub_dy = 2.54
    else:  # 'B'
        rel_x = -half_w + comp_pin_data['pos_mm']
        rel_y = -half_h - pin_len
        stub_dx = 0
        stub_dy = -2.54

    return (comp_pos[0] + rel_x, comp_pos[1] + rel_y, stub_dx, stub_dy)


def compute_body_h(pins):
    """Replicate body_h calculation from make_ic_symbol."""
    side_pos = {'L': [], 'R': []}
    for p in pins:
        if p['side'] in side_pos:
            side_pos[p['side']].append(p['pos_mm'])
    max_left = max(side_pos['L']) if side_pos['L'] else 0
    max_right = max(side_pos['R']) if side_pos['R'] else 0
    return max(max_left, max_right) + 5.08


# ---------------------------------------------------------------------------
# S-expression emitters
# ---------------------------------------------------------------------------

def emit_symbol_instance(lib_id, ref, value, footprint, pos, mirror=None):
    """Emit a (symbol ...) schematic instance."""
    u = uuid_from(f"sym-{ref}-{pos}")
    mirror_attr = f' (mirror {mirror})' if mirror else ''
    # Reference label position depends on symbol; use a default offset above
    return f'''  (symbol (lib_id "{lib_id}") (at {pos[0]:.3f} {pos[1]:.3f} 0){mirror_attr} (unit 1)
    (in_bom yes) (on_board yes) (dnp no)
    (uuid "{u}")
    (property "Reference" "{ref}" (at {pos[0]:.3f} {pos[1] - 6.0:.3f} 0)
      (effects (font (size 1.27 1.27)))
    )
    (property "Value" "{value}" (at {pos[0]:.3f} {pos[1] + 6.0:.3f} 0)
      (effects (font (size 1.27 1.27)))
    )
    (property "Footprint" "{footprint}" (at {pos[0]:.3f} {pos[1]:.3f} 0)
      (effects (font (size 1.27 1.27)) hide)
    )
    (property "Datasheet" "" (at {pos[0]:.3f} {pos[1]:.3f} 0)
      (effects (font (size 1.27 1.27)) hide)
    )
    (instances
      (project "foxhunt-badge"
        (path "/{uuid_from('root-sheet')}"
          (reference "{ref}") (unit 1)
        )
      )
    )
  )'''


def emit_wire(p1, p2, seed):
    u = uuid_from(f"wire-{seed}-{p1}-{p2}")
    return f'''  (wire (pts (xy {p1[0]:.3f} {p1[1]:.3f}) (xy {p2[0]:.3f} {p2[1]:.3f}))
    (stroke (width 0) (type default))
    (uuid "{u}")
  )'''


def emit_label(text, pos, orient=0, seed=""):
    u = uuid_from(f"label-{text}-{pos}-{seed}")
    safe = text.replace('"', '\\"')
    # Justify based on orientation: 0=right (label points right), 180=left
    just = "left bottom" if orient == 0 else "right bottom"
    return f'''  (label "{safe}" (at {pos[0]:.3f} {pos[1]:.3f} {orient})
    (effects (font (size 1.27 1.27)) (justify {just}))
    (uuid "{u}")
  )'''


def emit_global_label(text, pos, orient=0, seed=""):
    """Used for power nets that span the whole sheet."""
    u = uuid_from(f"glabel-{text}-{pos}-{seed}")
    safe = text.replace('"', '\\"')
    just = "left" if orient == 0 else "right"
    return f'''  (global_label "{safe}" (shape input) (at {pos[0]:.3f} {pos[1]:.3f} {orient})
    (effects (font (size 1.27 1.27)) (justify {just}))
    (uuid "{u}")
  )'''


def emit_power(power_lib_id, ref, pos, orient=0):
    """Emit a power symbol instance like +3V3 or GND."""
    u = uuid_from(f"pwr-{ref}-{pos}")
    return f'''  (symbol (lib_id "{power_lib_id}") (at {pos[0]:.3f} {pos[1]:.3f} {orient}) (unit 1)
    (in_bom yes) (on_board yes) (dnp no)
    (uuid "{u}")
    (property "Reference" "{ref}" (at {pos[0]:.3f} {pos[1] - 5.0:.3f} 0)
      (effects (font (size 1.27 1.27)) hide)
    )
    (property "Value" "{power_lib_id.split(':')[-1]}" (at {pos[0]:.3f} {pos[1] + 3.0:.3f} 0)
      (effects (font (size 1.27 1.27)))
    )
    (property "Footprint" "" (at 0 0 0) (effects (font (size 1.27 1.27)) hide))
    (property "Datasheet" "" (at 0 0 0) (effects (font (size 1.27 1.27)) hide))
    (instances
      (project "foxhunt-badge"
        (path "/{uuid_from('root-sheet')}"
          (reference "{ref}") (unit 1)
        )
      )
    )
  )'''
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

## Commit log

2026-04-26 DC710 badge — DEF CON 34 (B-2 Spirit)
    - 200x77mm B-2 silhouette PCB extracted from STL mesh (3 aft spikes,
    engine cutouts, swept leading edges) — real B-2 proportions.
    - ESP32-C3-MINI-1 + SA868-V VHF + SSD1306 OLED + 4x WS2812 + LiPo.
    - Schematic ERC-clean (0 errors / 0 warnings).
    - Freerouting v2.1.0 routed 128 of 131 nets (577 tracks + 63 GND vias).
    - Reproducible Python generators (lib_gen, footprint_gen, sch_gen,
    pcb_gen, generate_b2_outline) using b2.stl as outline source.
    - Official Espressif ESP32-C3-MINI-1 footprint (53 pads, datasheet pinout).
    - DEF CON 33 design moved to defcon33/.
    [b2_outline.dxf, bom.csv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]
2026-04-26 README: cropped board renders + official blueprint views
    - images/badge_top.png and images/badge_bottom.png: user-cropped 3D renders
    - images/badge_front_blueprint.png and images/badge_back_blueprint.png:
    official KiCad-plotted PCB blueprints (rev 0.6) converted from PDF
2026-04-26 Schematic: use stock power symbols (GND/+3V3/VBUS) for power nets
    [foxhunt-badge.kicad_sch]
